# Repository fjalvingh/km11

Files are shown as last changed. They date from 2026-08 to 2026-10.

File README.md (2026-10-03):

# Pdp-11 KM11 Maintenance Module with LCD screen

This is supposed to become a KM11 maintenance module. It is a 2 slot card which should 
be placed in both KM11 slots of a PDP 11/05 or 11/10. It uses an ATTINY1616 (or 3216 
if I cannot make the code fit) and a set of i2c I/O adapters (PCF8574T) to read the data
from both slots for the KM11, and writes those to an LCD screen, offset on a cable.

The main PCB must be placed in the PDP 11/05. The LCD display and the switches sit on
a second, small PCB (`kicad/kmdisp`) at the end of a 20-way ribbon cable, so they can be
outside the pdp/11 in the 3D-printed console from `3d/`.

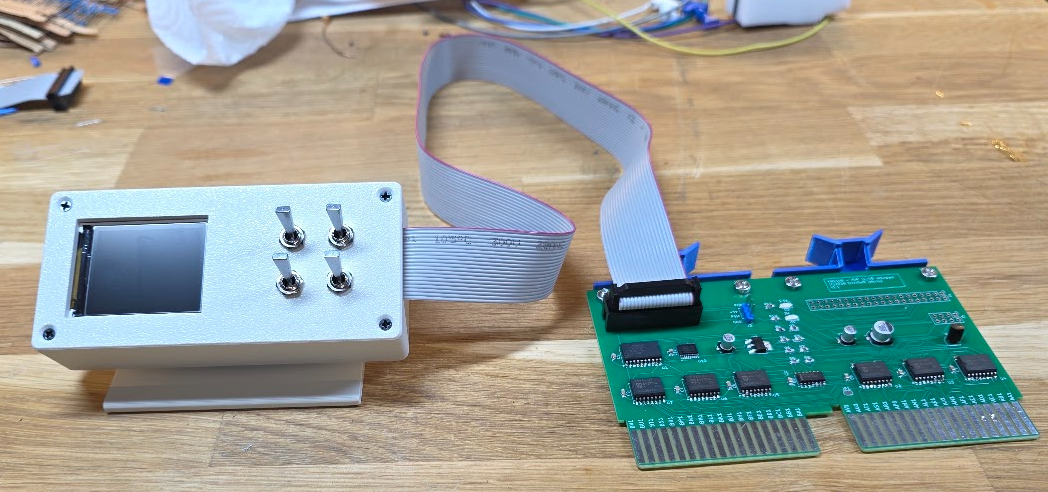
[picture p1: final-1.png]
The final version, in its 3d printed housing


## Hardware

The board uses:

* An ATTINY1616 (or ATTINY3216) as the controller
* Six PCF8574T I2C extenders to connect to both KM11 slots
* A 1.8" 160x128 LCD display to show the data

## Schematic and PCB views, version 1.1

The first version had some small issues which were repaired in this version.

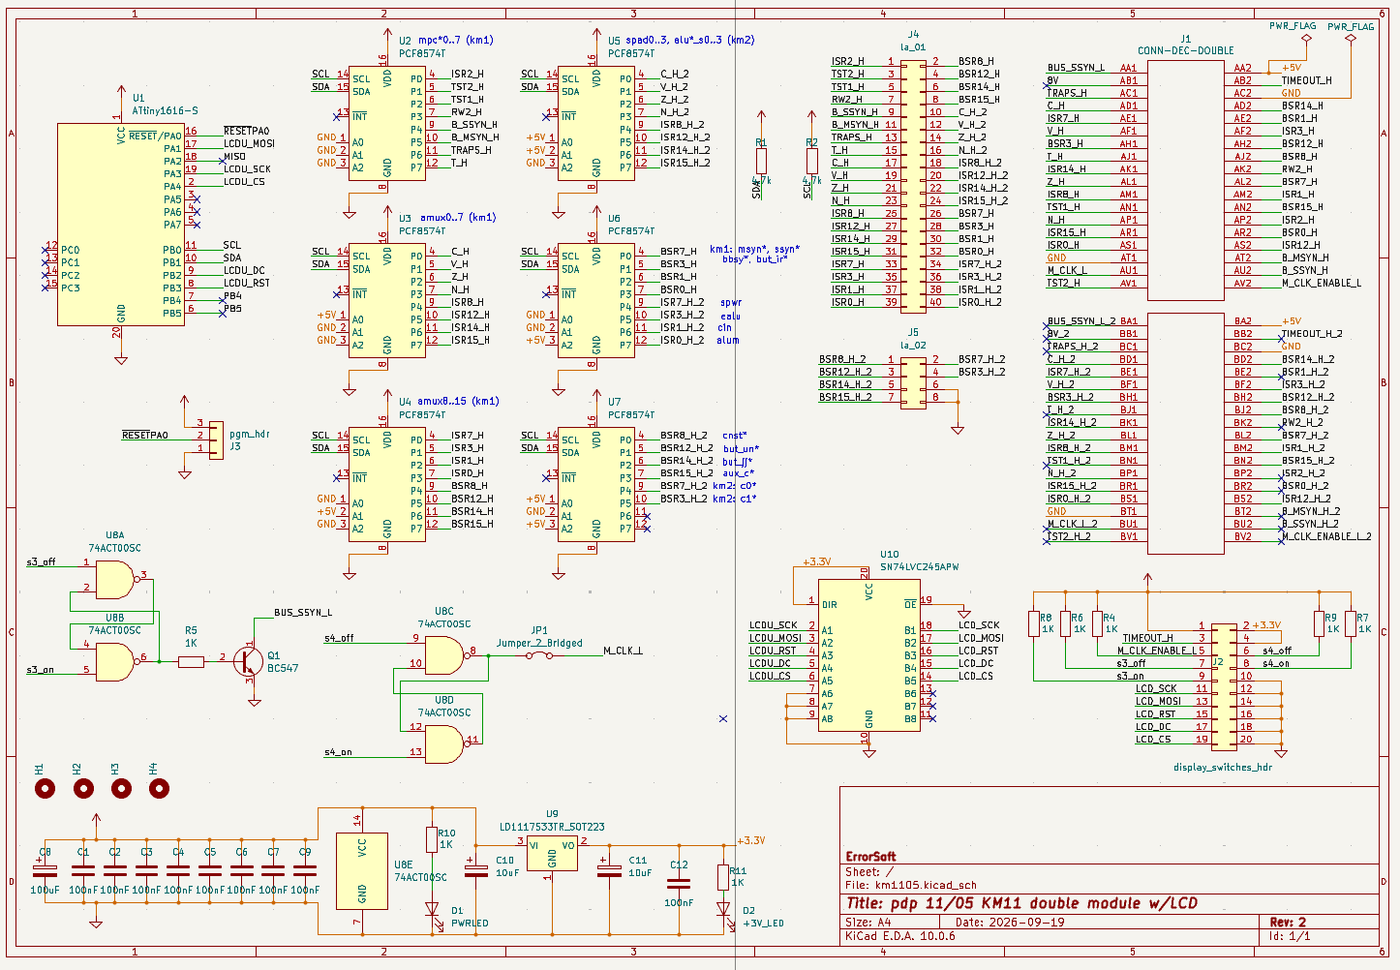
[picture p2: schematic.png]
schematic


## Display and switches board

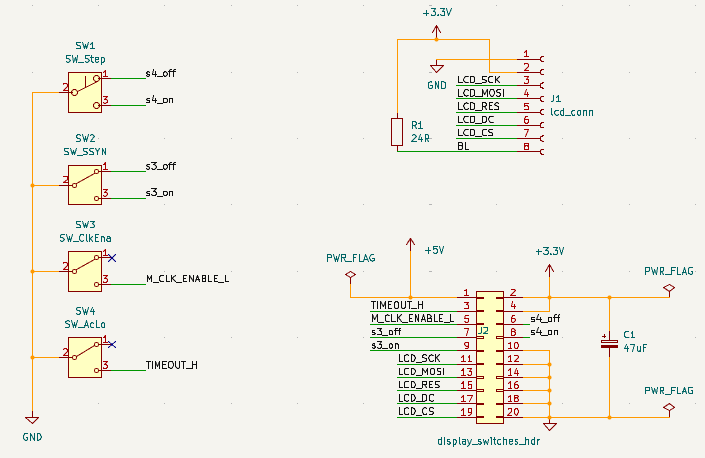
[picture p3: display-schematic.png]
The schematic for the display and switches board which resides in the housing


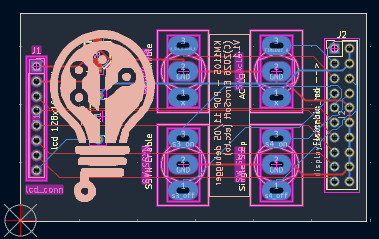
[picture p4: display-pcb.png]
The PCB for the display and switches board


## Code

The code was partially created by Claude, and does not use the usual libraries to save space 
in the Flash memory of the ATTINY1616 as it only has 16K. The code directly accesses registers
to control both the ST7735 LCD controller and the I2C extenders, and contains two fonts (5x7 
and 8x16).

At the time of writing the code takes about 9.3KB of the 16KB Flash available.

The code is a loop that reads all six extenders about ten times a second and repaints only
what changed. An earlier version of the screen, before the layout described below:

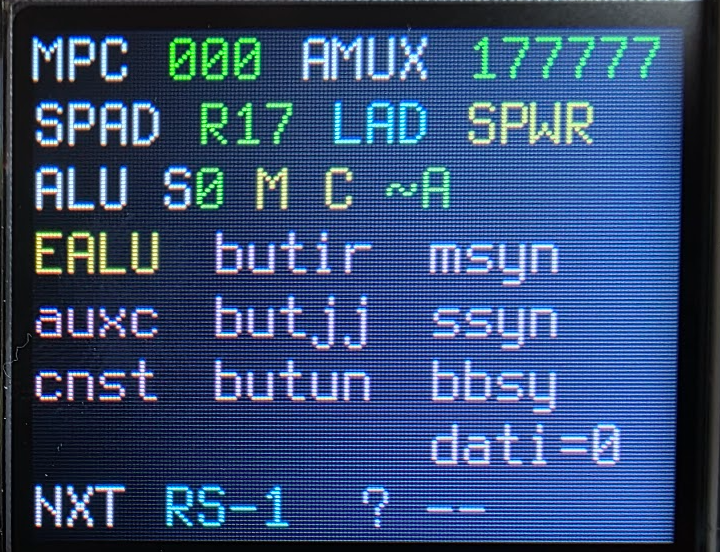
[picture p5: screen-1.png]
The screen, on a non-inserted card


### What the screen shows

```
MPC 302  AMUX 000000
SPAD R7  PC  spwr
ALU SF M c A
EALU BUTIR msyn
auxc butjj ssyn
cnst butun bbsy
          dati=0
NXT H-2  E OK
```

* **MPC** – the microprogram counter (octal). This is the *next* microstep, not the one whose
  signals are on the rest of the screen (KD11-B manual EK-KD11B-MM-001, 5.9).
* **AMUX** – the 16-bit data path (octal).
* **SPAD** – the scratchpad register being addressed, numbered as DEC does (R0–R17), with its
  use: SP, PC, SRC (R10), DST (R11), VEC (R12) or LAD (R17). Then SPWR, the scratchpad write.
* **ALU** – S, the raw S3–S0 function select (hex), then M (mode) and C (carry in), then the 74181 function they select (for example `A+B+1`). The function is grey when EALU is off, because then the ALU result does not reach the AMUX.
* **Flags**, in three columns: ALU/data path (EALU, AUXC, CNST), the microprogram branch tests
  (BUTIR, BUTJJ, BUTUN), and the Unibus (MSYN, SSYN, BBSY). Below the Unibus column is the bus
  cycle from C1/C0 with its code: DATI=0, DATIP=1, DATO=2, DATOB=3. The cycle name is lit while
  MSYN is asserted.
* **NXT** – DEC's name for the microstep the MPC points at, as used in the microprogram flow
  charts.
* **Status** (bottom right) – the microcode revision and the result of the microcode check (see
  below). A red `I2C:` followed by U numbers replaces it when an extender does not answer; the
  values that extender supplies are then not real.

Signals that are active low on the backplane (and shown dim on the original KM11, like the MPC
and ALU S) are inverted first, so everything on the screen is the logical value. Single signals
are **yellow and upper case** when asserted, **red and lower case** when negated.

Colours that mark a value:

* **dark blue background** – changed since the machine last moved. When single stepping, this
  shows what the last step did, and it stays until the next step.
* **white on red** – does not match the microcode listing (see below).

### Microcode check

While the processor is single stepped (M CLK ENABLE on, M CLK PULSE to step), the firmware
compares the lamps with DEC's microcode listing for the microword that just executed. It checks
ALU S/M/C, the scratchpad address, the four BUT lamps and AUXC. The status shows:

| Status | Meaning |
| --- | --- |
| `E OK` / `F OK` | the lamps match the listing |
| `E BAD` | some lamps do not match; they are drawn white on red |
| `SEQ?` | the MPC moved to an address the previous microword cannot branch to; the MPC turns red |
| `--` | nothing to check: no step seen yet, or the clock is running |

The first letter is the microcode revision of the M7261: `E` (1973) or `F` (1976), or `?` until
it is known. The card finds out by itself. The two revisions differ only in 14 microwords, and
the first time a step passes one of them, the AUXC lamp shows which revision is installed. Unary
instructions (CLR, INC, COM…) pass them. The revision is kept in the ATtiny's EEPROM.
`make REV=E eeprom`, `make REV=F eeprom` or `make REV=AUTO eeprom` sets or forgets it. Uploading
new firmware erases it, and it is learnt again.

The four switches are BUS SSYN, AC LO, M CLK PULSE (STEP) and M CLK ENABLE. The AC LO one sits
on the KM11 pin the 11/20 used for NO TIMEOUT, and the net is still called `TIMEOUT_H` for that
reason; on the 11/05 throwing it asserts BUS AC LO and starts the power-fail sequence.

`review.md` records the September 2026 check of the design and firmware against DEC's own
documentation, with the sources.

## Help with microcode debugging

The PDP 11/05 microcode for Rev.E and Rev.F can be browsed easily using [the microcode browser for the PDP 11/05](https://tools.etc.to/).

## Programming

To program the ATTINY1616 please follow the setup and instructions from [my 8bit bus display tool](https://github.com/fjalvingh/8bit-busdisplay). The source code is under src/. Two steps to do for a build:

* Use `make` to build the code, then
* Use `make upload` to upload the code to the board (with the programmer connected, obviously).

## The prototype

I made a small test setup to test driving the display:

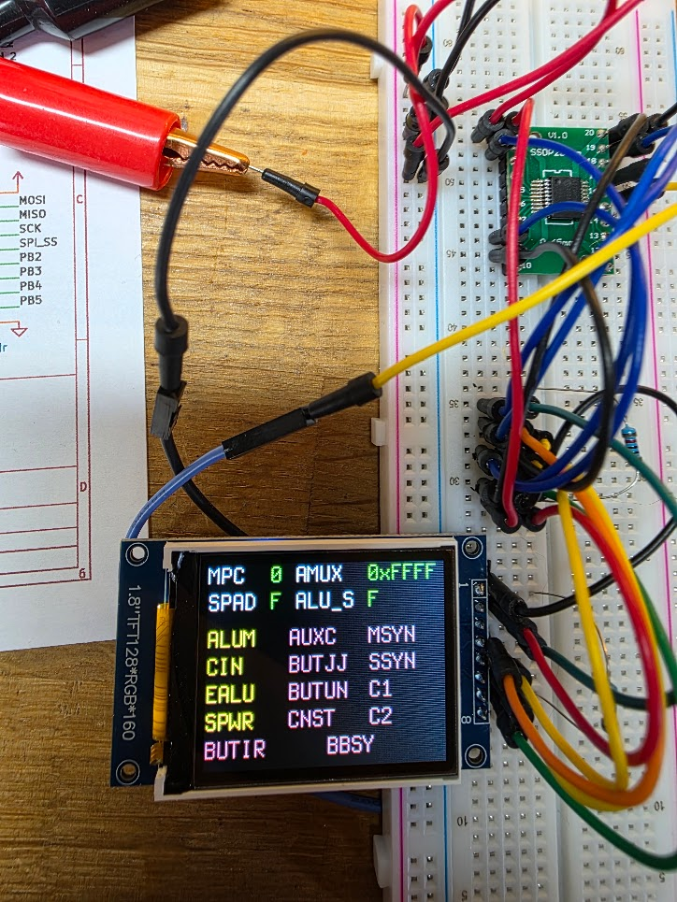
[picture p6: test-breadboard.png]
test setup


The initial idea was to use a fancy 2.25 landscape mode LCD to show the info, but after almost 4 hours
of testing and messing around with the code I gave up, I assume the display I got was defective. I was not helped by the fact that the second display tested, now the 1.8" display, was ALSO found to be defective, wasting another few hours. In the end I proved that of the 5 1.8" displays I have 1 was defective, and I had to pick that one for the test, obviously. Murphy in full working order.

## The first version in an actual PDP 11/10 (same as 11/05)

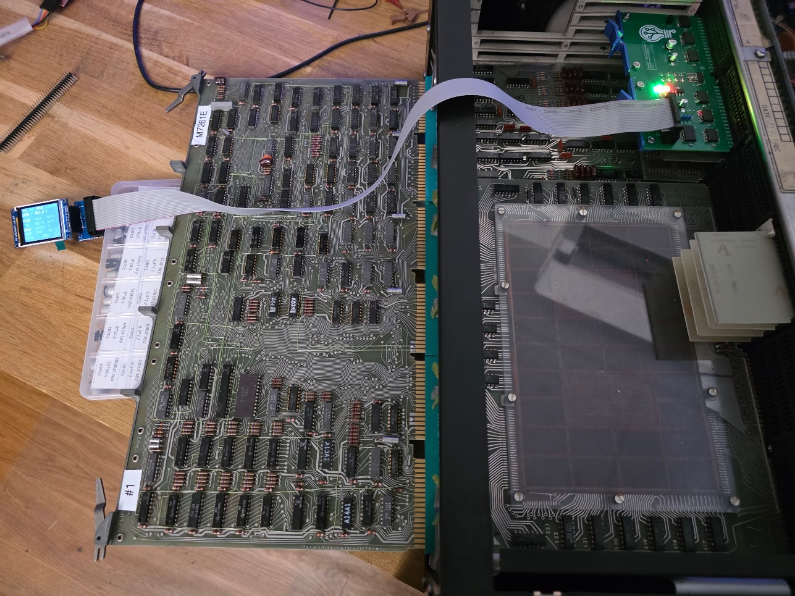
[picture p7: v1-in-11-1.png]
The V1 version in a PDP 11/10. This does not yet have its housing.


More closeup:

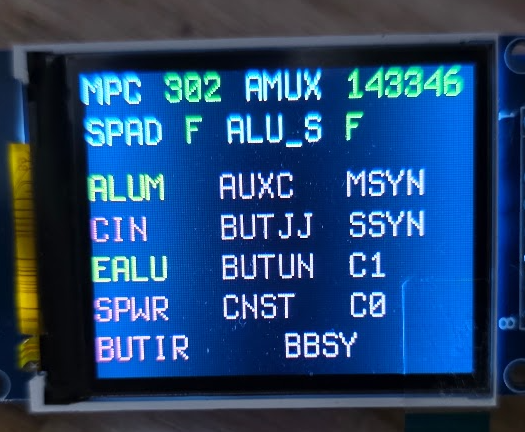
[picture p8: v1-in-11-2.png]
The old style display. On the side you can see the M7261 board on an extender

The microcode PC is at 302~oct~, which is H-2, part of the HALT instruction.

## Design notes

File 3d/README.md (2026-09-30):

# KM11 display console

Tilted desk console for the KM11's remote display: the display board
(`kicad/kmdisp`) carrying a 1.8" 128x160 ST7735S SPI TFT mounted landscape and
four MTS-102 toggle switches, on a ribbon cable back to the card.

`console.py` is the parametric source (CadQuery). Everything is driven from the
PARAMETERS block at the top; change a number and re-run.

## Parts

| STL | Size | Print orientation |
|---|---|---|
| `console_panel.stl` | 118.4 x 56 x 3.2 mm | face on the bed |
| `console_base.stl` | 118.4 x 56 x 22.8 mm | floor on the bed, walls up |
| `console_pedestal.stl` | 86 x 73.5 x 33.3 mm | as exported, base on the bed |

`console_assembly.stl` is for looking at only — do not slice it.

Assembled: **118.4 x 73.5 x 56 mm**, panel tilted 30 degrees off horizontal with
the back edge raised.

The panel is a flat plate. The base is the floor plus all four walls, with a
screw stud in each corner; the panel screws down onto them.

## What fixes the geometry

The switch holes and the display window are where the display board puts the
switches and the LCD; they must not move. `console.py` holds the board's KiCad
coordinates (`kc_sw`, `kc_board`, `kc_j2`) and places the board by its switch
cluster, so the checks it prints (board to walls, board to studs) come from the
real layout. The board spans x = -2.39 .. 56.99 mm in box coordinates, past
where the old right wall stood, which is why the box grew 4.4 mm on the right.
The left edge did not move.

The board hangs off the panel by its switches. Nothing else touches it. The
studs sit in the corners, 1.3–1.5 mm clear of its front and back edges.

## The ribbon

J2 is on the board's panel side, so the IDC plug's back, where the cable
leaves it, is just under the panel. Crimp the plug so the cable leaves toward
the switches' side (+x). It then runs flat out through a 27 x 3 mm notch at
the top of the right wall, centred on J2 (y = 15 .. 42 mm). The panel closes
the notch, so the cable is laid in rather than threaded through.

## How the display mounts

The glass stands 2.25 mm proud of its PCB and drops into the window from behind.
The window is cut to the measured glass outline (43.7 x 34.05 + 0.3 mm per
side), so nothing overlaps the glass. The module sits on the display board's
socket, so how far into the window it reaches depends on the board and socket
heights, not on the console.

## Print settings

PLA, 0.2 mm layer, 3 walls, 20% gyroid infill, **no supports**, no brim.

In its export orientation, no face on any part overhangs by more than 45 degrees
from vertical. Only the panel's edge chamfer and screw countersinks reach 45
degrees, because they are on the bed side. Don't re-orient the parts in the
slicer. Use 3 walls rather than 2, because the switch bushings, the panel screws
and the pedestal screws all thread into printed plastic.

## Hardware

- 8 x M3 countersunk self-tapping screws: 4 x 12 mm (panel to base studs),
  4 x 10 mm (base to pedestal)
- 4 x MTS-102 toggle switches with their nuts and washers, on the display board

## Assembly

1. Offer the base up to the pedestal and drive four M3 x 10 from inside the
   base into the pedestal. They are countersunk, so the heads end flush with
   the floor under the display board.
2. Fit the display board to the panel: toggles through their holes with the
   nuts on the outside, LCD glass in the window.
3. Plug in the ribbon, cable leaving toward the switches.
4. Lay the ribbon in the notch in the right wall and drop the panel onto the
   base. Then drive the four M3 x 12 corner screws into the studs.

## Check before printing

- **Depth.** The cavity is 18.8 mm from the panel's underside to the floor.
  The board, socket and switch stack were not measured into the model. Check
  that the back of the display board and its solder joints clear the floor, and
  that the pedestal screw heads under it are flush. If not, raise `box_t`.
- **Notch height.** `cable_h` = 3 mm assumes the IDC plug's back comes within a
  couple of mm of the panel. If the plug sits lower, the ribbon has to rise to
  the notch. Deepen the notch if that bend is too sharp.

## Panel layout

Measured from the panel's front-left corner, looking at the panel:

- display window 44.30 x 34.65 mm, spanning x = 10.05 .. 54.35 mm, y = 10.68 .. 45.33 mm
- switch holes 6.4 mm dia at x = 82.5 / 98.5 mm, y = 20 / 36 mm
- corner screws 5.4 mm in from the left and right edges, at y = 5.5 / 50.5 mm

## Regenerating

```bash
cd 3d
.venv/bin/python run_cadquery_model.py console.py --preview --strict
```

`run_cadquery_model.py`, `preview.py` and `mesh_io.py` are the headless
render helpers; they write `console_*_preview.png` next to each STL.

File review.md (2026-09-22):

# Design review, 22 September 2026

A check of the card (`kicad/km1105`), the display board (`kicad/kmdisp`) and the firmware (`src/`)
against DEC's own PDP-11/05 documentation. The fixes listed at the end were applied the same day;
the findings are kept here as the record of what was checked and why.

## Sources

All scans on bitsavers are images without a text layer, and the server answers a plain `curl` with
403: fetch with a browser `User-Agent`.

- **EK-KD11B-MM-001**, *KD11-B Processor Maintenance Manual*, January 1975.
  `https://www.bitsavers.org/pdf/dec/pdp11/1105/EK-KD11B-MM-001_Jan75.pdf`.
  Section 5.9 *KM11 Maintenance Panel*, 5.10 *Using KM11 Maintenance Panel*, Figure 5-1 (the KM-1
  and KM-2 overlays with DEC's B/D marks: *bright* / *dim when asserted*) and Table 5-4 (what every
  lamp and switch means). PDF pages 97–100.
- **PDP-11/05 engineering drawings, rev AH**, July 1976.
  `https://www.bitsavers.org/pdf/dec/pdp11/1105/1105_RevAH_Engineering_Drawings_Jul76.pdf`.
  The overlay drawings themselves, A-SS-5509081-0-9 (KM1) and -0-10 (KM2), PDF pages 186–187; the
  microprogram flow K-MP-KD11-B-1, pages 34–45, which is where the MPC values come from.
- **KM11 Maintenance Panel**, May 1970.
  `https://www.bitsavers.org/pdf/dec/pdp11/KM11_Maintenance_Panel_May70.pdf`.
  The W130 / W131 prints, D-BS-KM11-0-MB: which connector pin drives which lamp, the lamp
  positions on the W131, and the switch circuit.
- Jörg Hoppe's KM11 replica, `/d1/hobby/MiniMainframes/pdp/joerg_km11/`: the schematic the `J1`
  pin names were taken from, and his 11/05 overlay.
- `kicad-cli sch erc` / `pcb drc` on both boards, a parsed netlist of both, and a full firmware
  rebuild (`make -B`).

## Verified correct

- **Every `J1` pin name matches the W130 print**, pin for pin: BSR0 H = R2, BSR1 H = E2,
  BSR3 H = H1, BSR7 H = L2, BSR15 H = N2, BSR14 H = D2, BSR12 H = H2, BSR8 H = J2, ISR0 H = S1,
  ISR1 H = M2, ISR3 H = F2, ISR7 H = E1, ISR15 H = R1, ISR14 H = K1, ISR12 H = S2, ISR8 H = M1,
  N H = P1, Z H = L1, V H = F1, C H = D1, T H = J1, TRAPS H = C1, B MSYN H = T2, B SSYN H = U2,
  R/W2 H = K2, TST1 H = N1, TST2 H = V1, ISR2 H = P2; M CLK L = U1, M CLK ENABLE L = V2,
  TIME OUT H = B2, BUS SSYN L = A1, +5 V = A2, +8 V = B1, GND = C2 and T1.
- **The whole of `km11-signals.txt`** — all 28 lamps for both KM-1 and KM-2 — matches DEC's
  overlays. The W131 placement drawing puts lamp I1 at the *top* of the right-hand column and I25
  at the top left, with switches S3 (BUS SSYN), S1 (B2), S4 (M CLK), S2 (M CLK ENABLE) in exactly
  the positions Figure 5-1 draws BUS SSYN / AC LO / M CLK PULSE / M CLK EN, which fixes the
  orientation. Every one of the 48 expander inputs in the netlist lands on the pin `mapping.txt`
  says, so the card reads precisely what the overlay shows. Nothing is swapped, nothing is missing.
- KM-1 is wired to row A and KM-2 to row B of the same slot (manual §5.9 g), so the double-height
  card's A connector = KM-1 = the unsuffixed nets, B = KM-2 = the `_2` nets.
- The KM-2 MSYN and SSYN lamps that are left unconnected are "same as MSYN on KM-1" (Table 5-4).
  The MPC "is duplicated on both KM11 slots", so reading it once is enough.
- Polarity: MPC (D), BUT IR / BBUSY / SSYN / MSYN (D), AUX C / BUT JJ / BUT UN / CNST (D),
  C1 / C0 (D) are inverted by the firmware; AMUX (B), SPAD (B), ALUM / CIN / EALU / SPWR (B) are
  not. All agree with the overlay — except ALU S, see below.
- PCF8574 addresses 0x20–0x25 match the A0–A2 strapping of U2–U7. TWI0 on PB0/PB1 and SPI0 on
  PA1/PA3/PA4 are the ATtiny1616 default positions. U10 (74LVC245): DIR high, OE low, unused A
  inputs grounded, 5 V-tolerant inputs on a 3.3 V supply.
- The switch circuit is the W131 circuit: a cross-coupled 7400 latch driving M CLK L straight from
  a totem-pole output, a transistor pulling BUS SSYN L, a pull-up on M CLK ENABLE L, none on B2.
  Driving `M_CLK_L` from a 74ACT00 output is therefore by the book. The manual (§4.5) confirms
  M CLK L is an input to E039 pin 12 on the M7261; nothing on the processor drives it.
- On the display board the SPDT common (pin 2, the centre pad of the MTS-102 footprint) is ground
  in all four switches, matching the W131.
- ERC: six warnings only (dangling no-connect flags; LVC245 inputs tied to ground). DRC: one
  dangling via on `ISR1_H`. The display board is clean.
- Firmware: builds without warnings, 3998 bytes flash, 14 bytes RAM.

## Errors found

### 1. `ALU_S` polarity wrong in the firmware

DEC marks ALU S3–S0 "D" on the KM-2 overlay: dim when asserted, so the pin carries the signal
active low, exactly like MPC. `km11-signals.txt` and the README both say so. But
`src/signals.cpp` had `invertMask[3] = 0x00` ("SPAD and ALU_S, straight") because `mapping.txt`
had lost the star on `ALU_S`. The screen showed the complement of the ALU function code.

### 2. MPC truncated on screen, and shown in the wrong base

`kmmain.cpp` formatted the 8-bit MPC as two *decimal* digits, so anything from 100 up lost its
hundreds digit: the console halt loop at 300₈ / 302₈ (192 / 194) displayed as "92" / "94". DEC's
flow charts and §5.10 quote the MPC in octal ("the MPC should read 321₈, which is the contents of
the NXT field of LOC 100₈"), and 8 bits need three octal digits. AMUX was hex; the console lights
and everything in the manual are octal.

### 3. "C2" is DEC's "C0"

Table 5-4: "BUS C1 and C0 together signify the type of Unibus cycle": C1 C0 = 00 DATI, 01 DATIP,
10 DATO, 11 DATOB. The signal was called C2 in `km11-signals.txt`, `mapping.txt`, `signals.h`, on
the schematic and on the screen. The wire (U7 P4) is right, only the name was wrong. Jörg's
overlay has the same slip, which is where it came from.

### 4. The fourth switch is AC LO, not "No Timeout"

On the 11/05, KM11 pin B2 is BUS AC LO: "When actuated in the direction of the arrow (ON), AC LO
asserts BUS AC LO as long as the switch is ON" (Table 5-4; drawing 5509081-0-9 says the same). The
TIME OUT meaning belongs to the 11/20's W131. The display board called it `SW_NoTimeout` with a
"No Timeout" silkscreen. Throwing it starts the power-fail sequence. Note also §5.9 b: with the
manual clock enabled, bus error timeouts are disabled anyway, so a "no timeout" switch would be
redundant on this machine. The net keeps its historical name `TIMEOUT_H`; the labels say AC LO.

## Minor

- `kmmain.cpp` and the `Makefile` said U1 runs at 3.3 V; U1's VCC is +5 V in the netlist. The
  /2 prescaler is still fine, the reasoning was stale.
- §5.9 e: the MPC lamps show the address of the *next* microstep, not the current one.
- `pcfStatus` is computed but never shown. An expander that stops answering reads 0xFF, so its
  active-low flags silently show as negated. Some indicator would help. *(open)*
- There is no I²C bus recovery. If the ATtiny resets mid-read — UPDI programming does that — a
  PCF8574 can hold SDA low and every transaction then times out until a power cycle. Nine SCL
  pulses before `twiInit()` would clear it. *(open)*
- M CLK PULSE takes two ON/OFF throws per processor clock (§5.10). A momentary (ON)-OFF toggle
  for SW1 would be kinder than the MTS-102 ON-ON. *(open)*

## Fixes applied

- `src/signals.cpp`: `invertMask[3]` is `0xf0`, ALU_S inverted; comments corrected.
- `src/kmmain.cpp`: MPC three octal digits, AMUX six octal digits (`formatOctal`); "C2" → "C0";
  the 3.3 V comment corrected.
- `src/signals.h`: `SIG_C2` → `SIG_C0`, comments.
- `src/Makefile`: the 3.3 V comment corrected.
- `mapping.txt`, `km11-signals.txt`: `C2*` → `C0*`, `ALU_S*` marked active low.
- `kicad/km1105/km1105.kicad_sch`: annotation text "km2: c2*" → "km2: c0*".
- `kicad/kmdisp/kmdisp.kicad_sch`, `kmdisp.kicad_pcb`: SW4 is `SW_AcLo`, silkscreen "AC LO".
- `README.md`, `CLAUDE.md`: C0, AC LO, octal, "next microstep" noted.

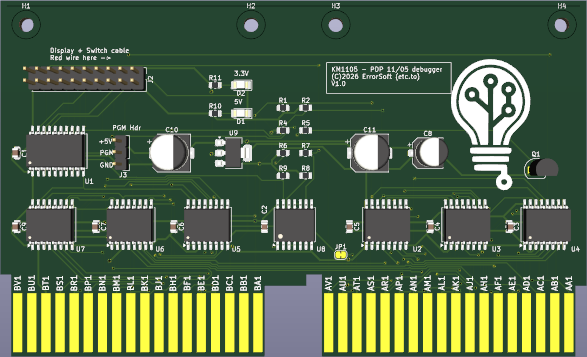
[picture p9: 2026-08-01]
3dview.png

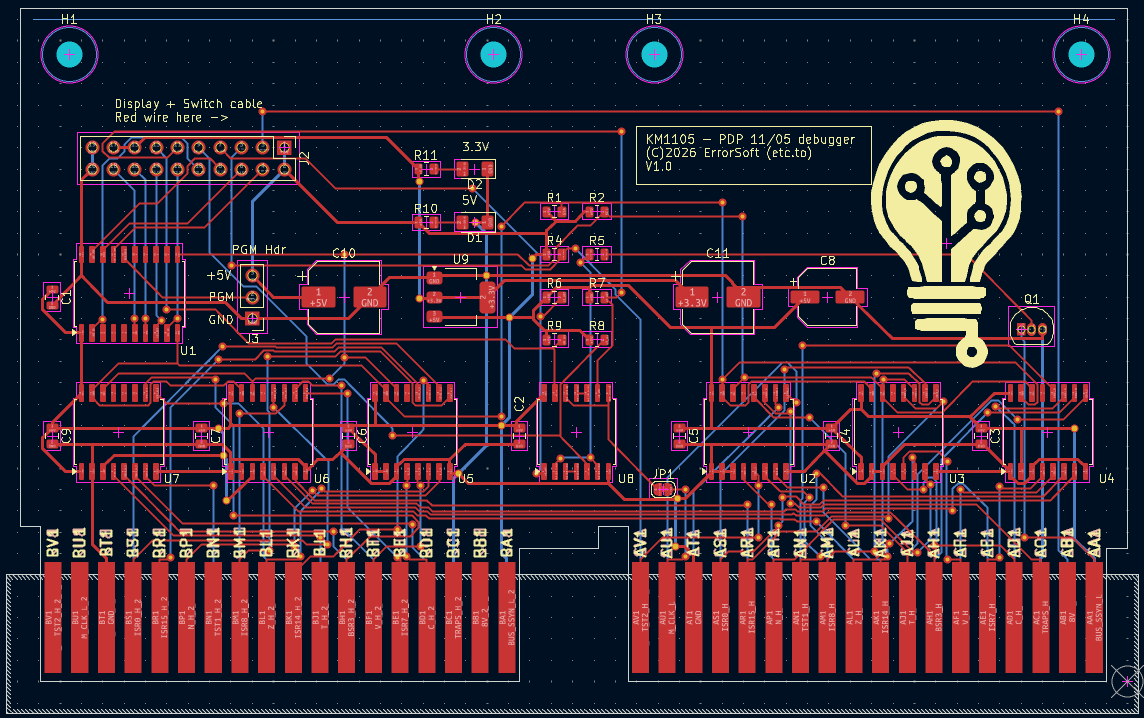
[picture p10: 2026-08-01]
pcblayout.png

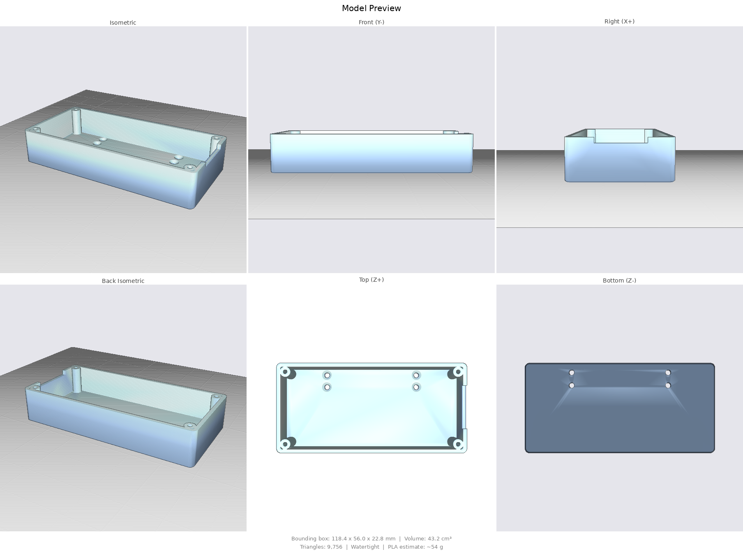
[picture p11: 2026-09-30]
3d/console_base_preview.png

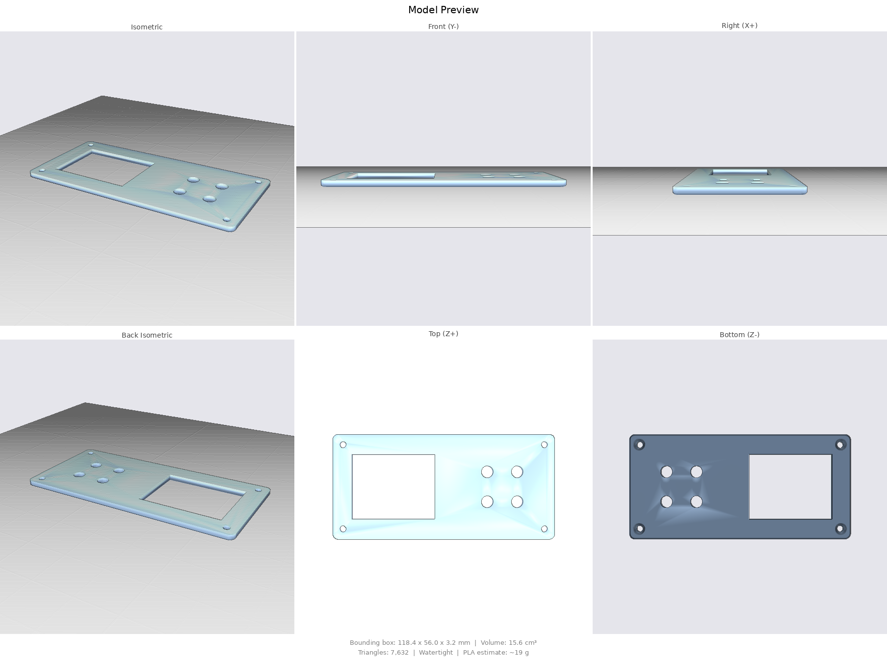
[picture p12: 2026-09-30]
3d/console_panel_preview.png

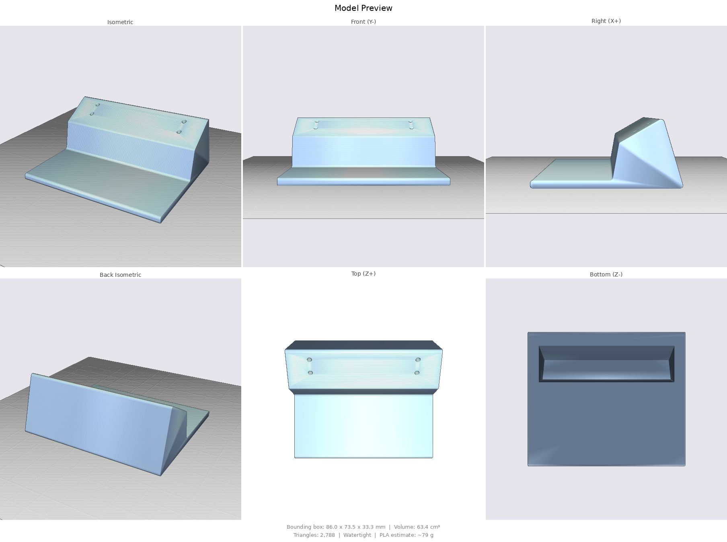
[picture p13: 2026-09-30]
3d/console_pedestal_preview.png

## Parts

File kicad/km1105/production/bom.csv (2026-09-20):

Designator | Footprint | Quantity | Value | LCSC Part #
C1, C12, C2, C3, C4, C5, C6, C7, C9 | 0805 | 9 | 100nF
C10, C11 | CP_Elec_4x4.5 | 2 | 10uF
C8 | CP_Elec_6.3x7.7 | 1 | 100uF
D1 | 1206 | 1 | PWRLED
D2 | 1206 | 1 | +3V_LED
J1 | CONN-DEC-DOUBLE | 1 | CONN-DEC-DOUBLE
J2 | PinHeader_2x10_P2.54mm_Vertical | 1 | display_switches_hdr
J3 | PinHeader_1x03_P2.54mm_Vertical | 1 | pgm_hdr
J4 | PinHeader_2x20_P2.54mm_Vertical | 1 | la_01
J5 | PinHeader_2x04_P2.54mm_Vertical | 1 | la_02
JP1 | SolderJumper-2_P1.3mm_Bridged_RoundedPad1.0x1.5mm | 1 | Jumper_2_Bridged
Q1 | TO-92_Inline | 1 | BC547
R1, R2 | 0805 | 2 | 4.7k
R10, R11, R4, R5, R6, R7, R8, R9 | 0805 | 8 | 1K
U1 | SOIC-20W_7.5x12.8mm_P1.27mm | 1 | ATtiny1616-S
U10 | TSSOP-20_4.4x6.5mm_P0.65mm | 1 | SN74LVC245APW
U2, U3, U4, U5, U6, U7 | SOIC-16W_7.5x10.3mm_P1.27mm | 6 | PCF8574T
U8 | SO-14_3.9x8.65mm_P1.27mm | 1 | 74ACT00SC
U9 | SOT-223-3_TabPin2 | 1 | LD1117S33TR_SOT223

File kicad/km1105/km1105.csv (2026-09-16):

Reference | Qty | Value | DNP | Exclude from BOM | Exclude from Board | Exclude from Simulation | Exclude from Position Files | Footprint | Datasheet
C1,C2,C3,C4,C5,C6,C7,C9 | 8 | 100nF |  |  |  |  | ${EXCLUDE_FROM_POS_FILES} | Capacitor_SMD:C_0805_2012Metric
C8 | 1 | 100uF |  |  |  |  | ${EXCLUDE_FROM_POS_FILES} | Capacitor_SMD:CP_Elec_6.3x7.7
C10,C11 | 2 | 10uF |  |  |  |  | ${EXCLUDE_FROM_POS_FILES} | Capacitor_SMD:CP_Elec_8x5.4
D1 | 1 | PWRLED |  |  |  |  | ${EXCLUDE_FROM_POS_FILES} | LED_SMD:LED_1206_3216Metric_Pad1.42x1.75mm_HandSolder
D2 | 1 | +3V_LED |  |  |  |  | ${EXCLUDE_FROM_POS_FILES} | LED_SMD:LED_1206_3216Metric_Pad1.42x1.75mm_HandSolder
J1 | 1 | CONN-DEC-DOUBLE |  |  |  |  | ${EXCLUDE_FROM_POS_FILES} | DEC-FLIP-CHIP:CONN-DEC-DOUBLE
J2 | 1 | display_switches_hdr |  |  |  |  | ${EXCLUDE_FROM_POS_FILES} | Connector_PinHeader_2.54mm:PinHeader_2x10_P2.54mm_Vertical
J3 | 1 | pgm_hdr |  |  |  |  | ${EXCLUDE_FROM_POS_FILES} | Connector_PinHeader_2.54mm:PinHeader_1x03_P2.54mm_Vertical
JP1 | 1 | Jumper_2_Bridged |  |  |  |  | ${EXCLUDE_FROM_POS_FILES} | Jumper:SolderJumper-2_P1.3mm_Bridged_RoundedPad1.0x1.5mm
Q1 | 1 | BC547 |  |  |  |  | ${EXCLUDE_FROM_POS_FILES} | Package_TO_SOT_THT:TO-92_Inline | https://www.onsemi.com/pub/Collateral/BC550-D.pdf
R1,R2 | 2 | 4.7k |  |  |  |  | ${EXCLUDE_FROM_POS_FILES} | Resistor_SMD:R_0805_2012Metric
R4,R5,R6,R7,R8,R9,R10,R11 | 8 | 1K |  |  |  |  | ${EXCLUDE_FROM_POS_FILES} | Resistor_SMD:R_0805_2012Metric
U1 | 1 | ATtiny1616-S |  |  |  |  | ${EXCLUDE_FROM_POS_FILES} | Package_SO:SOIC-20W_7.5x12.8mm_P1.27mm | http://ww1.microchip.com/downloads/en/DeviceDoc/ATtiny3216_ATtiny1616-data-sheet-40001997B.pdf
U2,U3,U4,U5,U6,U7 | 6 | PCF8574T |  |  |  |  | ${EXCLUDE_FROM_POS_FILES} | Package_SO:SOIC-16W_7.5x10.3mm_P1.27mm | https://www.nxp.com/docs/en/data-sheet/PCF8574_PCF8574A.pdf
U8 | 1 | 74ACT00SC |  |  |  |  | ${EXCLUDE_FROM_POS_FILES} | Package_SO:SOIC-14W_7.5x9mm_P1.27mm | http://www.ti.com/lit/gpn/sn74ls00
U9 | 1 | LD1117S33TR_SOT223 |  |  |  |  | ${EXCLUDE_FROM_POS_FILES} | Package_TO_SOT_SMD:SOT-223-3_TabPin2 | http://www.st.com/st-web-ui/static/active/en/resource/technical/document/datasheet/CD00000544.pdf

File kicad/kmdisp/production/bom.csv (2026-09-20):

Designator | Footprint | Quantity | Value | LCSC Part #
C1 | CP_Elec_4x3.9 | 1 | 47uF
J1 | PinSocket_1x08_P2.54mm_Vertical | 1 | lcd_conn
J2 | PinHeader_2x10_P2.54mm_Vertical | 1 | display_switches_hdr
R1 | R_Axial_DIN0207_L6.3mm_D2.5mm_P7.62mm_Horizontal | 1 | 24R
SW1 | SW_Toggle_MTS102 | 1 | SW_Step
SW2 | SW_Toggle_MTS102 | 1 | SW_SSYN
SW3 | SW_Toggle_MTS102 | 1 | SW_ClkEna
SW4 | SW_Toggle_MTS102 | 1 | SW_NoTimeout

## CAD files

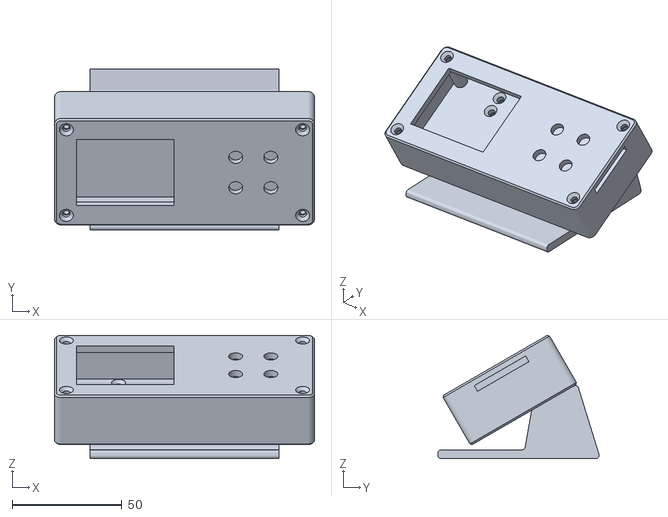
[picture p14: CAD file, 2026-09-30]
3d/console_assembly.stl
118.4 x 73.5 x 56.1

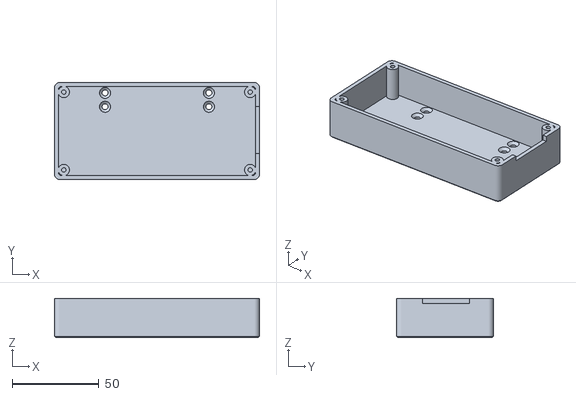
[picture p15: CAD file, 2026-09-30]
3d/console_base.stl
118.4 x 56.0 x 22.8

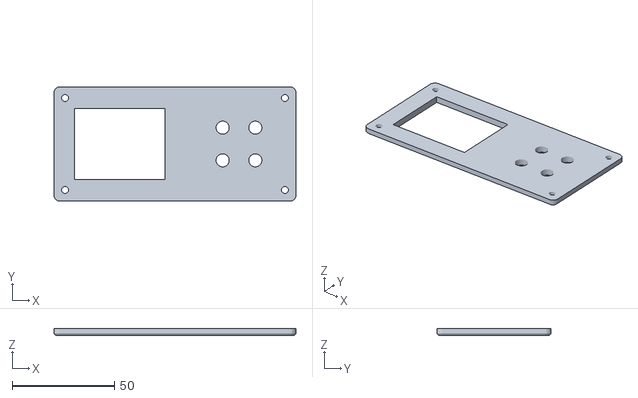
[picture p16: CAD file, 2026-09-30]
3d/console_panel.stl
118.4 x 56.0 x 3.20

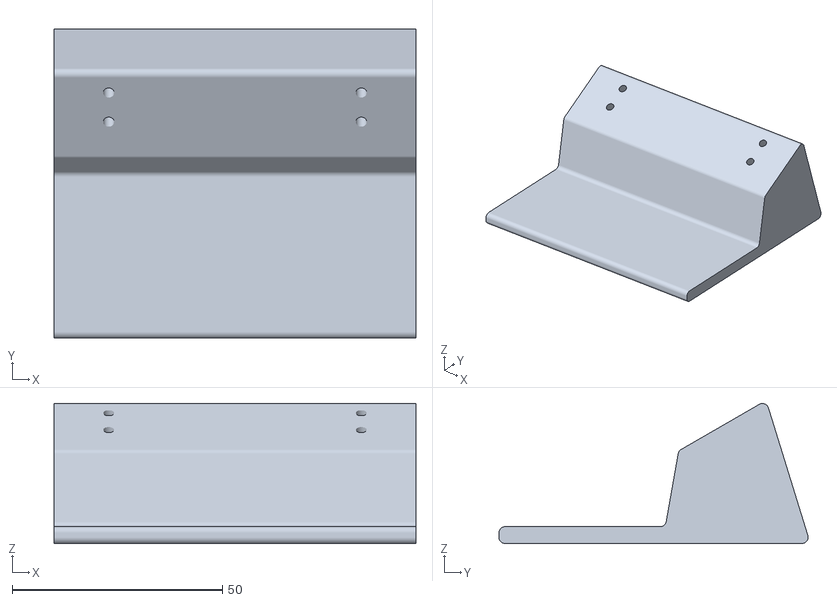
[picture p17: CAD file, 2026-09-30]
3d/console_pedestal.stl
86.0 x 73.5 x 33.3

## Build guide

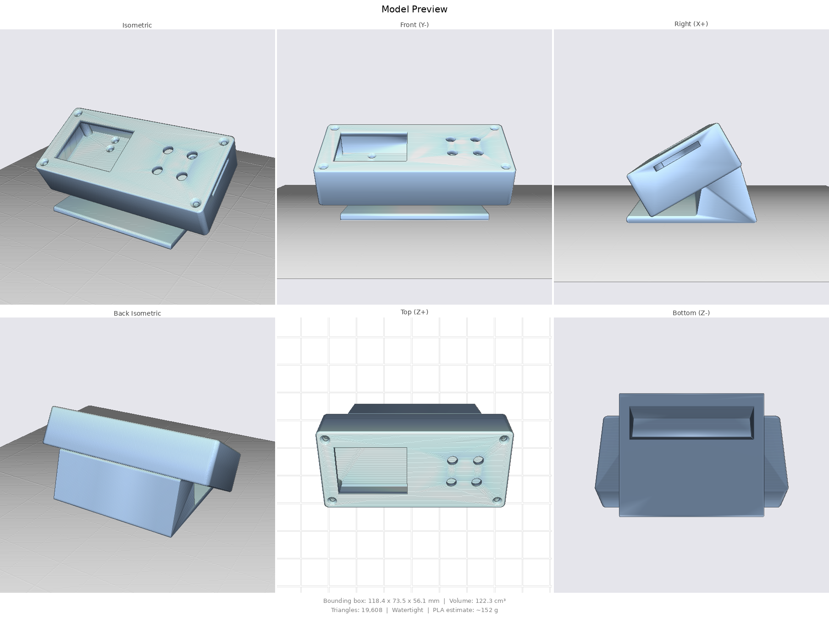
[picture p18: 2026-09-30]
3d/console_assembly_preview.png

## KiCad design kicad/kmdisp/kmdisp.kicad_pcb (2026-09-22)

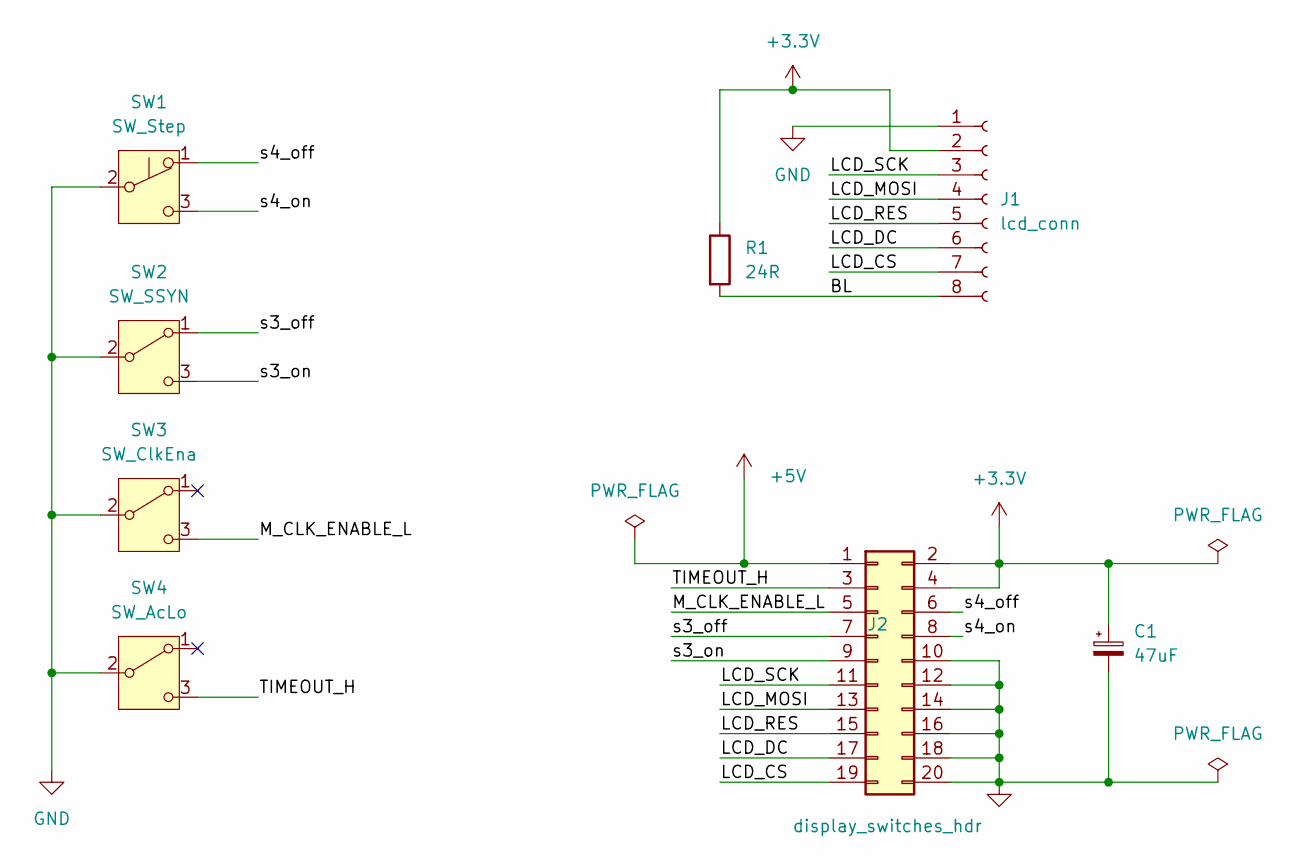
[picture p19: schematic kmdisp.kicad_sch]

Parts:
C1: 47uF; CP_Elec_4x3.9
J1: lcd_conn; PinSocket_1x08_P2.54mm_Vertical
J2: display_switches_hdr; PinHeader_2x10_P2.54mm_Vertical
R1: 24R; R_Axial_DIN0207_L6.3mm_D2.5mm_P7.62mm_Horizontal
SW1: SW_Step; SW_Toggle_MTS102
SW2: SW_SSYN; SW_Toggle_MTS102
SW3: SW_ClkEna; SW_Toggle_MTS102
SW4: SW_AcLo; SW_Toggle_MTS102

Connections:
+3.3V: C1.1, J1.2, J2.2, J2.4, R1.1
+5V: J2.1
/BL: J1.8, R1.2
/LCD_CS: J1.7, J2.19
/LCD_DC: J1.6, J2.17
/LCD_MOSI: J1.4, J2.13
/LCD_RES: J1.5, J2.15
/LCD_SCK: J1.3, J2.11
/M_CLK_ENABLE_L: J2.5, SW3.3 (C)
/TIMEOUT_H: J2.3, SW4.3 (C)
/s3_off: J2.7, SW2.1 (A)
/s3_on: J2.9, SW2.3 (C)
/s4_off: J2.6, SW1.1 (A)
/s4_on: J2.8, SW1.3 (C)
GND: C1.2, J1.1, J2.10, J2.12, J2.14, J2.16, J2.18, J2.20, SW1.2 (B), SW2.2 (B), SW3.2 (B), SW4.2 (B)

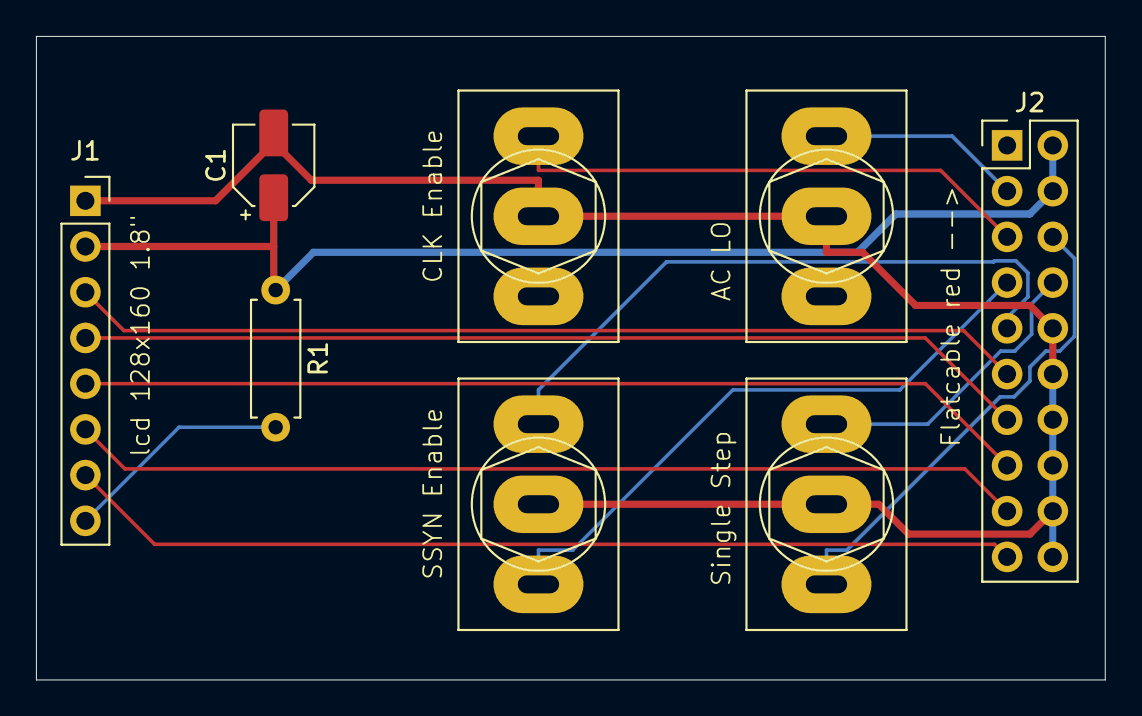
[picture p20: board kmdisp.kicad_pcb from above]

Board: 2 copper layers, 59.4 x 35.8 mm, 8 parts (0 on the bottom side), 14 nets.

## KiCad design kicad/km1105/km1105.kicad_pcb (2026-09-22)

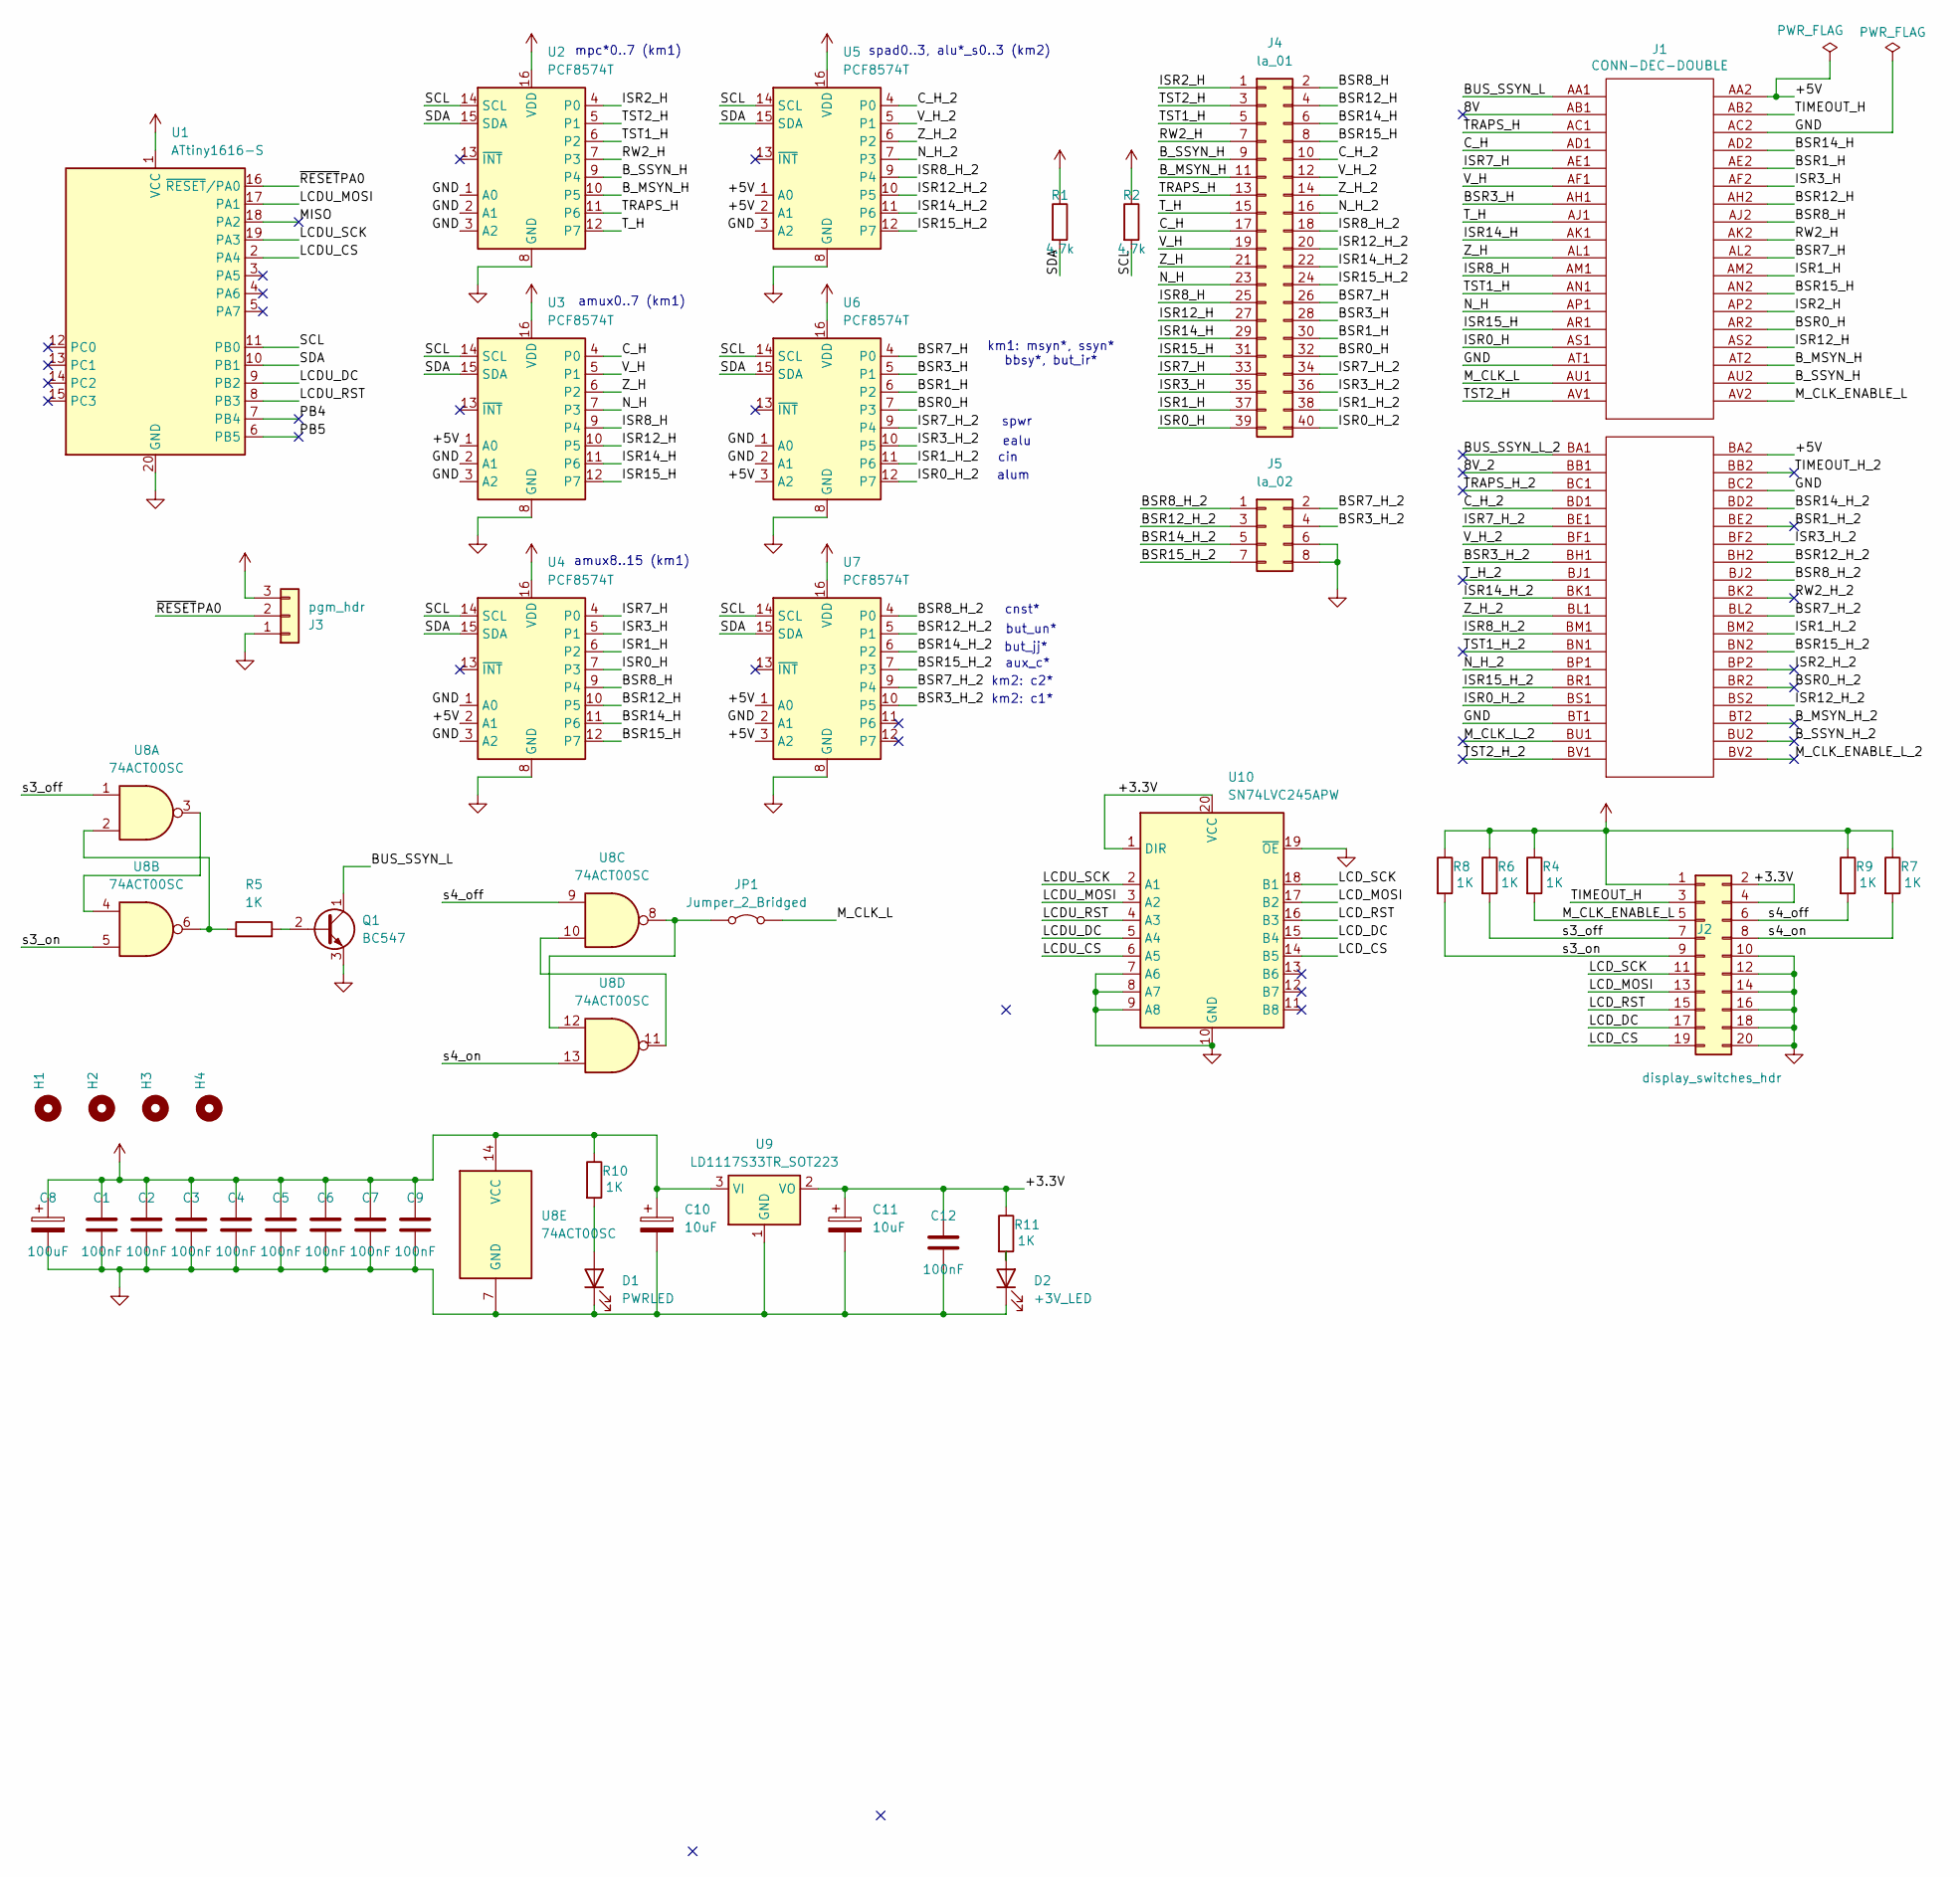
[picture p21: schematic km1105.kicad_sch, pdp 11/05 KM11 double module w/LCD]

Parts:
C1, C2, C3, C4, C5, C6, C7, C9, C12: 100nF; C_0805_2012Metric
C8: 100uF; CP_Elec_6.3x7.7
C10, C11: 10uF; CP_Elec_4x4.5
D1: PWRLED; LED_1206_3216Metric_Pad1.42x1.75mm_HandSolder
D2: +3V_LED; LED_1206_3216Metric_Pad1.42x1.75mm_HandSolder
H1, H2, H3, H4: MountingHole_3.2mm_M3
J1: CONN-DEC-DOUBLE
J2: display_switches_hdr; PinHeader_2x10_P2.54mm_Vertical
J3: pgm_hdr; PinHeader_1x03_P2.54mm_Vertical
J4: la_01; PinHeader_2x20_P2.54mm_Vertical
J5: la_02; PinHeader_2x04_P2.54mm_Vertical
JP1: Jumper_2_Bridged; SolderJumper-2_P1.3mm_Bridged_RoundedPad1.0x1.5mm
Q1: BC547; TO-92_Inline
R1, R2: 4.7k; R_0805_2012Metric
R4, R5, R6, R7, R8, R9, R10, R11: 1K; R_0805_2012Metric
U1: ATtiny1616-S; SOIC-20W_7.5x12.8mm_P1.27mm
U2, U3, U4, U5, U6, U7: PCF8574T; SOIC-16W_7.5x10.3mm_P1.27mm
U8: 74ACT00SC; SO-14_3.9x8.65mm_P1.27mm
U9: LD1117S33TR_SOT223; SOT-223-3_TabPin2
U10: SN74LVC245APW; TSSOP-20_4.4x6.5mm_P0.65mm

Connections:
+5V: C1.1, C2.1, C3.1, C4.1, C5.1, C6.1, C7.1, C8.1, C9.1, C10.1, J1.AA2, J1.BA2, J2.1, J3.3, R1.1, R2.1, R4.1, R6.1, R7.1, R8.1, R9.1, R10.1, U1.1 (VCC), U2.16 (VDD), U3.1 (A0), U3.16 (VDD), U4.2 (A1), U4.16 (VDD), U5.1 (A0), U5.2 (A1), U5.16 (VDD), U6.3 (A2), U6.16 (VDD), U7.1 (A0), U7.3 (A2), U7.16 (VDD), U8.14 (VCC), U9.3 (VI)
/8V: J1.AB1
/8V_2: J1.BB1
/+3.3V: C11.1, C12.1, J2.2, J2.4, R11.1, U9.2 (VO), U10.1 (DIR), U10.20 (VCC)
/BSR0_H: J1.AR2, J4.32, U6.7 (P3)
/BSR0_H_2: J1.BR2
/BSR1_H: J1.AE2, J4.30, U6.6 (P2)
/BSR1_H_2: J1.BE2
/BSR3_H: J1.AH1, J4.28, U6.5 (P1)
/BSR3_H_2: J1.BH1, J5.4, U7.10 (P5)
/BSR7_H: J1.AL2, J4.26, U6.4 (P0)
/BSR7_H_2: J1.BL2, J5.2, U7.9 (P4)
/BSR8_H: J1.AJ2, J4.2, U4.9 (P4)
/BSR8_H_2: J1.BJ2, J5.1, U7.4 (P0)
/BSR12_H: J1.AH2, J4.4, U4.10 (P5)
/BSR12_H_2: J1.BH2, J5.3, U7.5 (P1)
/BSR14_H: J1.AD2, J4.6, U4.11 (P6)
/BSR14_H_2: J1.BD2, J5.5, U7.6 (P2)
/BSR15_H: J1.AN2, J4.8, U4.12 (P7)
/BSR15_H_2: J1.BN2, J5.7, U7.7 (P3)
/BUS_SSYN_L: J1.AA1, Q1.1 (C)
/BUS_SSYN_L_2: J1.BA1
/B_MSYN_H: J1.AT2, J4.11, U2.10 (P5)
/B_MSYN_H_2: J1.BT2
/B_SSYN_H: J1.AU2, J4.9, U2.9 (P4)
/B_SSYN_H_2: J1.BU2
/C_H: J1.AD1, J4.17, U3.4 (P0)
/C_H_2: J1.BD1, J4.10, U5.4 (P0)
/ISR0_H: J1.AS1, J4.39, U4.7 (P3)
/ISR0_H_2: J1.BS1, J4.40, U6.12 (P7)
/ISR1_H: J1.AM2, J4.37, U4.6 (P2)
/ISR1_H_2: J1.BM2, J4.38, U6.11 (P6)
/ISR2_H: J1.AP2, J4.1, U2.4 (P0)
/ISR2_H_2: J1.BP2
/ISR3_H: J1.AF2, J4.35, U4.5 (P1)
/ISR3_H_2: J1.BF2, J4.36, U6.10 (P5)
/ISR7_H: J1.AE1, J4.33, U4.4 (P0)
/ISR7_H_2: J1.BE1, J4.34, U6.9 (P4)
/ISR8_H: J1.AM1, J4.25, U3.9 (P4)
/ISR8_H_2: J1.BM1, J4.18, U5.9 (P4)
/ISR12_H: J1.AS2, J4.27, U3.10 (P5)
/ISR12_H_2: J1.BS2, J4.20, U5.10 (P5)
/ISR14_H: J1.AK1, J4.29, U3.11 (P6)
/ISR14_H_2: J1.BK1, J4.22, U5.11 (P6)
/ISR15_H: J1.AR1, J4.31, U3.12 (P7)
/ISR15_H_2: J1.BR1, J4.24, U5.12 (P7)
/LCDU_CS: U1.2 (PA4), U10.6 (A5)
/LCDU_DC: U1.9 (PB2), U10.5 (A4)
/LCDU_MOSI: U1.17 (PA1), U10.3 (A2)
/LCDU_RST: U1.8 (PB3), U10.4 (A3)
/LCDU_SCK: U1.19 (PA3), U10.2 (A1)
/LCD_CS: J2.19, U10.14 (B5)
/LCD_DC: J2.17, U10.15 (B4)
/LCD_MOSI: J2.13, U10.17 (B2)
/LCD_RST: J2.15, U10.16 (B3)
/LCD_SCK: J2.11, U10.18 (B1)
/MISO: U1.18 (PA2)
/M_CLK_ENABLE_L: J1.AV2, J2.5, R4.2
/M_CLK_ENABLE_L_2: J1.BV2
/M_CLK_L: J1.AU1, JP1.2 (B)
/M_CLK_L_2: J1.BU1
/N_H: J1.AP1, J4.23, U3.7 (P3)
/N_H_2: J1.BP1, J4.16, U5.7 (P3)
/PB4: U1.7 (PB4)
/PB5: U1.6 (PB5)
/RW2_H: J1.AK2, J4.7, U2.7 (P3)
/RW2_H_2: J1.BK2
/SCL: R2.2, U1.11 (PB0), U2.14 (SCL), U3.14 (SCL), U4.14 (SCL), U5.14 (SCL), U6.14 (SCL), U7.14 (SCL)
/SDA: R1.2, U1.10 (PB1), U2.15 (SDA), U3.15 (SDA), U4.15 (SDA), U5.15 (SDA), U6.15 (SDA), U7.15 (SDA)
/TIMEOUT_H: J1.AB2, J2.3
/TIMEOUT_H_2: J1.BB2
/TRAPS_H: J1.AC1, J4.13, U2.11 (P6)
/TRAPS_H_2: J1.BC1
/TST1_H: J1.AN1, J4.5, U2.6 (P2)
/TST1_H_2: J1.BN1
/TST2_H: J1.AV1, J4.3, U2.5 (P1)
/TST2_H_2: J1.BV1
/T_H: J1.AJ1, J4.15, U2.12 (P7)
/T_H_2: J1.BJ1
/V_H: J1.AF1, J4.19, U3.5 (P1)
/V_H_2: J1.BF1, J4.12, U5.5 (P1)
/Z_H: J1.AL1, J4.21, U3.6 (P2)
/Z_H_2: J1.BL1, J4.14, U5.6 (P2)
/s3_off: J2.7, R6.2, U8.1
/s3_on: J2.9, R8.2, U8.5
/s4_off: J2.6, R9.2, U8.9
/s4_on: J2.8, R7.2, U8.13
/~RESETPA0: J3.2, U1.16 (~RESET/PA0)
GND: C1.2, C2.2, C3.2, C4.2, C5.2, C6.2, C7.2, C8.2, C9.2, C10.2, C11.2, C12.2, D1.1 (K), D2.1 (K), J1.AC2, J1.AT1, J1.BC2, J1.BT1, J2.10, J2.12, J2.14, J2.16, J2.18, J2.20, J3.1, J5.6, J5.8, Q1.3 (E), U1.20 (GND), U2.1 (A0), U2.2 (A1), U2.3 (A2), U2.8 (GND), U3.2 (A1), U3.3 (A2), U3.8 (GND), U4.1 (A0), U4.3 (A2), U4.8 (GND), U5.3 (A2), U5.8 (GND), U6.1 (A0), U6.2 (A1), U6.8 (GND), U7.2 (A1), U7.8 (GND), U8.7 (GND), U9.1 (GND), U10.7 (A6), U10.8 (A7), U10.9 (A8), U10.10 (GND), U10.19 (~OE)
unnamed: D1.2 (A), R10.2
unnamed: D2.2 (A), R11.2
unnamed: JP1.1 (A), U8.8, U8.12
unnamed: Q1.2 (B), R5.2
unnamed: R5.1, U8.2, U8.6
unnamed: U8.3, U8.4
unnamed: U8.10, U8.11

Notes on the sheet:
cin
but_un*
km2: c1*
but_jj*
amux8..15 (km1)
spwr
ealu
alum
amux0..7 (km1)
km2: c2*
spad0..3, alu*_s0..3 (km2)
km1: msyn*, ssyn* bbsy*, but_ir*
aux_c*
mpc*0..7 (km1)
cnst*

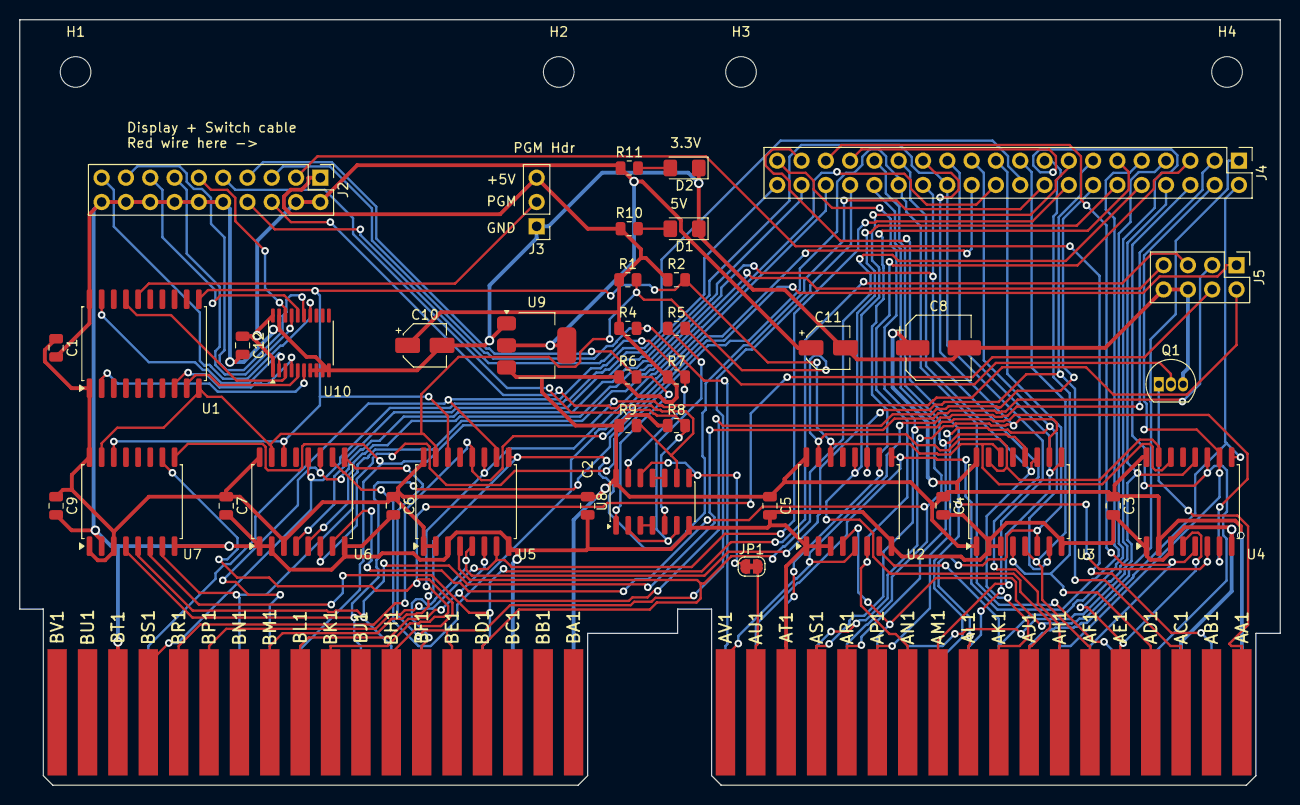
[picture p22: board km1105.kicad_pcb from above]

Board: 2 copper layers, 131.7 x 80.0 mm, 45 parts (0 on the bottom side), 77 nets.

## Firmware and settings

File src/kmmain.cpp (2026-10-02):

#include <avr/io.h>
#include <util/delay.h>
#include <avr/pgmspace.h>
#include <string.h>

#include "lcd.h"
#include "font5x7.h"
#include "pcf8574.h"
#include "signals.h"
#include "microtags.h"
#include "mcheck.h"

// The 20MHz fuse only selects the oscillator; the main clock still comes out of
// a divide-by-6 prescaler after reset, so the prescaler has to be set here for
// F_CPU (and with it _delay_ms and the SPI clock) to mean anything.
//
// It is set to divide by two, NOT switched off. U1 runs on +5V, so the part
// would be in spec at 20MHz, but nothing here needs it: 10MHz is plenty, the
// SPI and I2C dividers are tuned to it, and it keeps the edges on the ribbon
// gentler. If fuse2 is left at the 16MHz default this gives 8MHz instead,
// which is also fine - only the timings scale.
static void clockInit() {
	_PROTECTED_WRITE(CLKCTRL.MCLKCTRLB, CLKCTRL_PDIV_2X_gc | CLKCTRL_PEN_bm);
}

// One text line is FONT_HEIGHT pixels; leave one pixel of leading between them.
#define LINE_H (FONT_HEIGHT + 1)
static inline uint16_t lineY(uint8_t line, const Font *font = &FontSmall) {
	return (uint16_t) line * (font->height + 1);
}

static inline uint16_t lineX(uint8_t column, const Font *font = &FontSmall) {
	return (uint16_t) column * (font->width + 1);
}

// Unsigned decimal into a caller supplied buffer, right aligned in `width` and
// space padded. Small enough to be worth having instead of pulling in printf,
// which would cost well over a kilobyte of flash.
static void formatNumber(char *buf, uint16_t value, uint8_t width) {
	buf[width] = '\0';
	for(uint8_t i = width; i-- > 0;) {
		buf[i] = (char) ('0' + (value % 10));
		value /= 10;
		if(value == 0 && i > 0) {
			while(i-- > 0)
				buf[i] = ' ';
			break;
		}
	}
}

static void formatHex(char *buf, uint16_t value, uint8_t width) {
	buf[width] = '\0';
	for(uint8_t i = width; i-- > 0;) {
		int c = (value % 16);
		if(c > 9)
			c += 'A' - 10;
		else
			c += '0';

		buf[i] = (char) c;

		value /= 16;
		if(value == 0 && i > 0) {
			while(i-- > 0)
				buf[i] = '0';
			break;
		}
	}
}

// Zero padded octal, which is what everything PDP-11 is written in: the MPC
// addresses in the microprogram flow charts are octal, and so are the console
// lights the AMUX value gets compared with.
static void formatOctal(char *buf, uint16_t value, uint8_t width) {
	buf[width] = '\0';
	for(uint8_t i = width; i-- > 0;) {
		buf[i] = (char) ('0' + (value & 7));
		value >>= 3;
	}
}

// Paints a test pattern: a title, some coloured signal-ish text, and the whole
// printable character set laid out the way the signal display will use it.
static void drawTestScreen() {
	lcdFill(LCD_BLACK);

	lcdDrawText_P(0, lineY(0), PSTR("KM11 11/05 MAINT"), LCD_YELLOW, LCD_BLACK);

	lcdDrawText_P(0, lineY(1), PSTR("BSR"), LCD_GREY, LCD_BLACK);
	lcdDrawText_P(4 * FONT_CELL_W, lineY(1), PSTR("0000 1111"), LCD_GREEN, LCD_BLACK);
	lcdDrawText_P(0, lineY(2), PSTR("ISR"), LCD_GREY, LCD_BLACK);
	lcdDrawText_P(4 * FONT_CELL_W, lineY(2), PSTR("1010 0101"), LCD_RED, LCD_BLACK);

	// Every printable character, wrapped to the screen width. This is the part
	// that shows the font table and the glyph writer agree.
	uint8_t line = 4;
	uint16_t x = 0;
	for(uint8_t c = FONT_FIRST_CHAR; c <= FONT_LAST_CHAR; c++) {
		if(x + FONT_CELL_W > LCD_W) {
			x = 0;
			line++;
			if(lineY(line) + FONT_HEIGHT > LCD_H)
				break;
		}
		x = lcdDrawChar(x, lineY(line), (char) c, LCD_WHITE, LCD_BLACK);
	}
}

// Wiring test. No SPI, no protocol: SPI0 is switched off and all five lines to
// the display are toggled by hand, each at its own frequency, so any one of
// them can be identified on a slow scope or a multimeter without triggering on
// anything. Probe at the *display end* of the ribbon, not at the MCU:
//
//   CS   (PA4, J2.19, kmdisp J1.7)  8 Hz
//   MOSI (PA1, J2.13, kmdisp J1.4)  4 Hz
//   SCK  (PA3, J2.11, kmdisp J1.3)  2 Hz
//   DC   (PB2, J2.17, kmdisp J1.6)  1 Hz
//   RST  (PB3, J2.15, kmdisp J1.5)  0.5 Hz
//
// A line that does not move is a break between the pin and the panel. Check the
// amplitude while you are there: the lines leave the ATtiny at 5V and go
// through U10 (74LVC245 on 3.3V), so a 3.3V swing at the display end is right
// and a 5V one means the signal is bypassing U10.
__attribute__((unused)) static void pinTestLoop() {
	SPI0.CTRLA = 0;						// hand PA1/PA3 back to the port

	uint8_t tick = 0;
	for(;;) {
		if(tick & 0x01) LCD_SPI_PORT.OUTSET = LCD_CS_bm;    else LCD_SPI_PORT.OUTCLR = LCD_CS_bm;
		if(tick & 0x02) LCD_SPI_PORT.OUTSET = LCD_MOSI_bm;  else LCD_SPI_PORT.OUTCLR = LCD_MOSI_bm;
		if(tick & 0x04) LCD_SPI_PORT.OUTSET = LCD_SCK_bm;   else LCD_SPI_PORT.OUTCLR = LCD_SCK_bm;
		if(tick & 0x08) LCD_CTRL_PORT.OUTSET = LCD_DC_bm;   else LCD_CTRL_PORT.OUTCLR = LCD_DC_bm;
		if(tick & 0x10) LCD_CTRL_PORT.OUTSET = LCD_RST_bm;  else LCD_CTRL_PORT.OUTCLR = LCD_RST_bm;

		tick++;
		_delay_ms(62);
	}
}

// Read the controller back and report it on a spare pin, because with a dead
// panel there is nowhere else to put the answer. This is the test that decides
// whether the controller is listening at all: everything up to now has only
// proved the ATtiny is talking.
//
// The read is half duplex on SDA, since the module has no SDO pin. Watch PB5
// (U1 pin 6, spare, not on the ribbon) with the scope: each round is a 20ms
// high start marker, then 40 bits at 1ms each, MSB first, high = 1, so the
// five bytes can be read straight off the trace.
//
// Nothing is skipped for dummy clocks, so an answer may appear shifted a bit or
// a byte into the stream. What matters is the shape:
//
//   0x85 0x85 0x52 somewhere in it   an ST7789 answering. The controller is
//                                    alive and the fault is in the init values
//   any structured pattern           something is answering: send me the bytes
//   all ones                         nothing drives SDA back. Either the
//                                    controller ignores reads, or it is not
//                                    responding at all
//   all zeros                        SDA is being held low somewhere
__attribute__((unused)) static void idReportLoop() {
	LCD_CTRL_PORT.DIRSET = PIN5_bm;

	for(;;) {
		uint8_t id[5];
		lcdReadRegister(0x04, id, 5);	// RDDID

		LCD_CTRL_PORT.OUTSET = PIN5_bm;	// start marker
		_delay_ms(20);
		LCD_CTRL_PORT.OUTCLR = PIN5_bm;
		_delay_ms(5);

		for(uint8_t byte = 0; byte < 5; byte++) {
			for(uint8_t bit = 0; bit < 8; bit++) {
				if(id[byte] & (0x80 >> bit))
					LCD_CTRL_PORT.OUTSET = PIN5_bm;
				else
					LCD_CTRL_PORT.OUTCLR = PIN5_bm;
				_delay_ms(1);
			}
		}
		LCD_CTRL_PORT.OUTCLR = PIN5_bm;

		_delay_ms(500);
	}
}

// Panel bring-up mode. Set to 0 once the display works to get the text screen.
//
// The modes are a ladder, each dropping more assumptions than the last: the
// text screen needs everything to be right, mode 1 needs the geometry but not
// the font, mode 4 needs neither, mode 2 needs no SPI at all.
//
//   0 = the real text screen
//   1 = fill the panel with cycling colours, through the normal path
//   2 = pin wiggle, no SPI at all, for checking the wiring end to end
//   3 = read the controller ID back and report it on PB5
//   4 = flood the raw frame memory, ignoring panel size and offsets
//
// Set it in the Makefile (make DIAG_MODE=2); this is only the fallback for a
// compile that does not pass one.
#ifndef DIAG_MODE
	#define DIAG_MODE 1
#endif

// No white and no black in the cycle, deliberately. A pixel the controller
// never writes keeps whatever it last received, so with white in the rotation
// every missed pixel ends up white and stays white - which reads as "white
// lines" and hides which frame actually lost them. Against these four, a stale
// pixel shows up as the wrong colour instead.
static const uint16_t diagColors[4] = { LCD_RED, LCD_GREEN, LCD_BLUE, LCD_YELLOW };

// Fills the panel through the normal drawing path: real geometry, real offsets,
// real rotation. Once the controller is known to be alive this is the honest
// test, because it exercises exactly what the text screen will use.
//
// Every other pass draws stripes instead of a flat fill, one lcdFillRect per
// stripe, which is what tells the two failure modes apart:
//
//   stale pixels land on stripe boundaries   whole transactions are being lost,
//                                            so the fault is in the command or
//                                            window handling
//   stale pixels scattered inside stripes    bytes are being dropped mid
//                                            stream: a timing or signal
//                                            integrity problem, so try
//                                            LCD_SPI_DIV 64 or 128
__attribute__((unused)) static void diagLoop() {
	uint8_t ix = 0;
	for(;;) {
		lcdFill(diagColors[ix & 3]);
		_delay_ms(1000);

		// Eight pixel stripes, alternating, each its own window and RAMWR.
		for(uint16_t y = 0; y < LCD_H; y += 8) {
			uint16_t h = (y + 8 > LCD_H) ? (LCD_H - y) : 8;
			lcdFillRect(0, y, LCD_W, h, ((y >> 3) & 1) ? LCD_MAGENTA : LCD_CYAN);
		}
		_delay_ms(1000);

		ix++;
	}
}

// Fills the whole frame memory instead, ignoring panel size and offsets. Keep
// this for a panel that shows nothing at all; it addresses more memory than the
// glass has, so gaps and edge artefacts here do not necessarily mean anything
// is wrong with the drawing path.
__attribute__((unused)) static void ramFloodLoop() {
	uint8_t ix = 0;
	for(;;) {
		lcdInit();						// pulses RST every pass
		lcdFillRam(diagColors[ix]);
		ix++;
		if(ix >= 5)
			ix = 0;
		_delay_ms(1000);
	}
}

__attribute__((unused)) static void textLoop() {
	// Repaint forever rather than painting once and idling: on a scope or
	// analyser this gives a repeating SPI burst to trigger on, and on the panel
	// the counter proves the loop is still running even if the image is wrong.
	// The colour of the counter cycles too, so a frozen frame is obvious.
	static const uint16_t cycle[4] = { LCD_WHITE, LCD_GREEN, LCD_CYAN, LCD_MAGENTA };

	uint16_t frame = 0;
	for(;;) {
		drawTestScreen();

		char buf[6];
		formatNumber(buf, frame, 5);
		lcdDrawText_P(0, lineY(3), PSTR("FRAME"), LCD_GREY, LCD_BLACK);
		lcdDrawText(6 * FONT_CELL_W, lineY(3), buf, cycle[frame & 3], LCD_BLACK);

		frame++;
		_delay_ms(500);
	}
}

__attribute__((unused)) static uint8_t pcfStatus;
static uint16_t currentBg = LCD_BLACK;

// Background behind a value that differs from the machine state before the
// last change, so a single step shows what it moved. Dark enough that the
// red, yellow, green and cyan text stays readable on it.
static constexpr uint16_t LCD_HILITE = rgb565(0, 0, 150);

// Shows a flag in place: asserted is upper case in yellow, negated lower case
// in red, so the state reads even without the colour. Works on a RAM copy
// because it changes the case. Returns the x just past the text.
static uint16_t flagText(uint16_t x, uint16_t y, char *name, bool on, uint8_t style, const Font *font = &FontSmall);

// Same, for a name in flash.
static uint16_t flagDisp(uint16_t x, uint16_t y, const char *name, bool on, uint8_t style, const Font *font = &FontSmall) {
	char buf[8];
	strncpy_P(buf, name, sizeof buf - 1);
	buf[sizeof buf - 1] = '\0';
	return flagText(x, y, buf, on, style, font);
}

// How a value is drawn: plain, changed by the last step (dark blue behind
// it), or contradicting the microcode listing (white on red, which wins).
enum Style : uint8_t { ST_PLAIN, ST_CHANGED, ST_BAD };

static uint8_t styleOf(bool changed, bool bad) {
	return bad ? ST_BAD : changed ? ST_CHANGED : ST_PLAIN;
}

static uint16_t styleBg(uint8_t style) {
	return style == ST_BAD ? LCD_RED : style == ST_CHANGED ? LCD_HILITE : currentBg;
}

static uint16_t styleFg(uint8_t style, uint16_t fg) {
	return style == ST_BAD ? LCD_WHITE : fg;
}

static uint16_t flagText(uint16_t x, uint16_t y, char *name, bool on, uint8_t style, const Font *font) {
	if(!on) {
		for(char *p = name; *p != '\0'; p++)
			if(*p >= 'A' && *p <= 'Z')
				*p += 'a' - 'A';
	}
	return lcdDrawText(x, y, name, styleFg(style, on ? LCD_YELLOW : LCD_LIGHTRED), styleBg(style), font);
}

// The last sample off the expanders. Everything the screen draws comes out of
// here, so a failed read leaves the previous frame's numbers on the glass
// rather than blanking them.
__attribute__((unused)) static KmSignals currentSignals;
// The state before the last change, which drawScreen() highlights against.
__attribute__((unused)) static KmSignals previousSignals;

// Pads buf with spaces to `width` characters, so a short text overwrites a
// longer one left by the previous frame.
static void padTo(char *buf, uint8_t width) {
	uint8_t n = (uint8_t) strlen(buf);
	while(n < width)
		buf[n++] = ' ';
	buf[n] = '\0';
}

// What the processor keeps in each scratchpad register (KD11-B manual, Table
// 4-3). R13..R16 are unused. Three cells each so a shorter name overwrites a
// longer one.
static const char spadNames[16][4] PROGMEM = {
	"   ", "   ", "   ", "   ", "   ", "   ", "SP ", "PC ",
	"SRC", "DST", "VEC", "   ", "   ", "   ", "   ", "LAD",
};

// The 74181 functions as the KD11-B uses them: its A and B legs are active low
// (KD11-B manual 4.3.5), so this is the ACTIVE-LOW-DATA half of the 74181 truth
// table, where M high selects logic and CIN high adds one. Indexed by S3..S0 as
// the screen shows them (already inverted from the ALU S* lamps). "+" is
// addition, "|" OR; every DEC name in the microcode listing checks out against
// this table (A plus B = 9, A minus B minus 1 = 6, BL = 10, ABAR = 0, ...).
static const char aluLogic[16][7] PROGMEM = {
	"~A",     "~(A&B)", "~A|B",   "-1",     "~(A|B)", "~B",     "~(A^B)", "A|~B",
	"~A&B",   "A^B",    "B",      "A|B",    "0",      "A&~B",   "A&B",    "A",
};
// Arithmetic without carry in. With carry the result is one higher: a trailing
// "-1" is dropped, otherwise "+1" is appended.
static const char aluArith[16][11] PROGMEM = {
	"A-1",        "A&B-1",  "A&~B-1",     "-1",
	"A+(A|~B)",   "A&B+(A|~B)", "A-B-1",  "A|~B",
	"A+(A|B)",    "A+B",    "A&~B+(A|B)", "A|B",
	"A+A",        "A&B+A",  "A&~B+A",     "A",
};

// Cells left for the name on the ALU line. Five of the 32 arithmetic results
// have longer names ("A&~B+(A|B)+1" is 12); they show as "?", and the raw S,
// M and C beside them still say exactly what the ALU is doing. None of the
// five occurs in the microcode listing (the instruction-decode ROMs, which
// can also drive the ALU, are not transcribed).
#define ALU_NAME_W	9

// Names the ALU function into buf, space padded to ALU_NAME_W so it overwrites
// whatever the previous frame left there.
static void aluName(char *buf, uint8_t s, bool logic, bool carry) {
	uint8_t n;
	if(logic) {
		strcpy_P(buf, aluLogic[s]);
		n = strlen(buf);
	} else {
		strcpy_P(buf, aluArith[s]);
		n = strlen(buf);
		if(carry) {
			if(n == 2) {					// "-1" plus one
				strcpy(buf, "0");
				n = 1;
			} else if(buf[n - 2] == '-' && buf[n - 1] == '1') {
				n -= 2;
			} else {
				buf[n++] = '+';
				buf[n++] = '1';
			}
		}
	}
	if(n > ALU_NAME_W) {
		buf[0] = '?';
		n = 1;
	}
	while(n < ALU_NAME_W)
		buf[n++] = ' ';
	buf[n] = '\0';
}

// Everything on the main screen sits at a fixed place and is drawn only when
// what it shows changes, so a quiet machine costs no SPI traffic and a running
// one only repaints what moved. Each field remembers the key it was last drawn
// with: its value plus whether it is highlighted.
enum Field : uint8_t {
	F_MPC, F_AMUX, F_SPAD, F_SPWR, F_ALUS, F_ALUM, F_CIN, F_ALUNAME,
	F_EALU, F_AUXC, F_CNST, F_BUTIR, F_BUTJJ, F_BUTUN,
	F_MSYN, F_SSYN, F_BBSY, F_CYCLE, F_NXT, F_STATUS,
	F_COUNT
};

static uint32_t drawnKey[F_COUNT];
static bool screenDrawn;				// false: draw every field, and the labels

static bool fieldDue(Field f, uint32_t key) {
	if(screenDrawn && drawnKey[f] == key)
		return false;
	drawnKey[f] = key;
	return true;
}

static uint32_t fieldKey(uint16_t value, uint8_t style) {
	return (uint32_t) value | ((uint32_t) style << 16);
}

// Pixel layout: eight lines of the large font fill the 128 pixel height
// exactly, so lines are 16 apart with no extra gap. The font never uses the
// bottom row of its cell, which keeps the lines apart.
static const uint8_t ROW_H = 16;		// FontLarge.height
static const uint8_t GRID_Y = 3 * ROW_H;
static_assert(GRID_Y + 5 * ROW_H <= LCD_H, "the NXT line must be on the screen");
static const uint8_t GRID_COL1 = 45;
static const uint8_t GRID_COL2 = 99;

// One single-bit signal in the grid, highlighted when it changed.
struct GridFlag {
	const char *name;					// in flash
	uint16_t mask;
	uint8_t x;
	uint8_t row;
};

static const char nEALU[] PROGMEM = "EALU";
static const char nAUXC[] PROGMEM = "AUXC";
static const char nCNST[] PROGMEM = "CNST";
static const char nBUTIR[] PROGMEM = "BUTIR";
static const char nBUTJJ[] PROGMEM = "BUTJJ";
static const char nBUTUN[] PROGMEM = "BUTUN";
static const char nMSYN[] PROGMEM = "MSYN";
static const char nSSYN[] PROGMEM = "SSYN";
static const char nBBSY[] PROGMEM = "BBSY";

// One column per group: ALU and data path control, the microprogram branch
// tests, and the Unibus. In Field order from F_EALU on.
static const GridFlag gridFlags[] = {
	{ nEALU,  SIG_EALU,   0,         0 },
	{ nAUXC,  SIG_AUX_C,  0,         1 },
	{ nCNST,  SIG_CNST,   0,         2 },
	{ nBUTIR, SIG_BUT_IR, GRID_COL1, 0 },
	{ nBUTJJ, SIG_BUT_JJ, GRID_COL1, 1 },
	{ nBUTUN, SIG_BUT_UN, GRID_COL1, 2 },
	{ nMSYN,  SIG_MSYN,   GRID_COL2, 0 },
	{ nSSYN,  SIG_SSYN,   GRID_COL2, 1 },
	{ nBBSY,  SIG_BBSY,   GRID_COL2, 2 },
};

static void drawLabels(const Font *font) {
	lcdDrawText_P(0,  0,         PSTR("MPC"),  LCD_WHITE, currentBg, font);
	lcdDrawText_P(66, 0,         PSTR("AMUX"), LCD_WHITE, currentBg, font);
	lcdDrawText_P(0,  ROW_H,     PSTR("SPAD"), LCD_WHITE, currentBg, font);
	lcdDrawText_P(0,  2 * ROW_H, PSTR("ALU"),  LCD_WHITE, currentBg, font);
	lcdDrawText_P(32, 2 * ROW_H, PSTR("S"),    LCD_WHITE, currentBg, font);
	lcdDrawText_P(0,  GRID_Y + 4 * ROW_H, PSTR("NXT"), LCD_WHITE, currentBg, font);
}
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
int main() {
	resetDiag();
	clockInit();
	lcdInit();

#if DIAG_MODE == 4
	ramFloodLoop();
#elif DIAG_MODE == 3
	idReportLoop();
#elif DIAG_MODE == 2
	pinTestLoop();
#elif DIAG_MODE == 1
	diagLoop();
#else
#ifndef NO_I2C
	pcfInit();
	checkInit();
#endif
	lcdFill(LCD_BLACK);					// Clear screen
	for(;;) {
		// NO_I2C (make EXTRA=-DNO_I2C) leaves the expanders alone entirely, to
		// separate anything the bus does from anything the drawing does.
#ifndef NO_I2C
		KmSignals sample;
		pcfStatus = signalsRead(&sample);
		// Keep the state before the last change, not the last sample: when
		// single stepping the machine sits still between steps, and the
		// highlight has to stay until the next one.
		// The first sample has nothing to compare with and highlights nothing.
		static bool sampled;
		if(!sampled) {
			previousSignals = currentSignals = sample;
			sampled = true;
		} else if(!signalsEqual(sample, currentSignals)) {
			previousSignals = currentSignals;
			currentSignals = sample;
		}
		// A sample with an expander missing is not the machine: drop what the
		// check knows rather than learn from it.
		CheckResult check = { CHK_NONE, '?', 0, false, false };
		if(pcfStatus == 0)
			checkSample(sample, &check);
		else
			checkLost();
#else
		CheckResult check = { CHK_NONE, '?', 0, false, false };
#endif
		drawScreen(currentSignals, previousSignals, pcfStatus, check);
#if RESET_DIAG
		showResetDiag();
#endif
		_delay_ms(LOOP_DELAY_MS);
	}
	// textLoop();
#endif
}

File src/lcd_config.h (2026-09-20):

#ifndef LCD_CONFIG_H
#define LCD_CONFIG_H

// Hardware configuration for the KM11 display, taken from kicad/km1105 (the
// card) and kicad/kmdisp (the display board at the far end of the ribbon).
//
// The ATtiny1616 talks to the panel over SPI0 on its default port A mux, so no
// PORTMUX change is needed. Every display line leaves the ATtiny at 5V, goes
// through U10 (74LVC245 on the 3.3V rail) and reaches the ribbon header J2 at
// 3.3V; the display board's J2 has the same pinout and passes it straight to
// the module socket J1:
//
//   PA1  MOSI  -> U10 A2/B2 -> J2.13 -> kmdisp J1.4 (SDA)
//   PA2  MISO                            (unused by the display, it is write-only;
//                                         not on the ribbon)
//   PA3  SCK   -> U10 A1/B1 -> J2.11 -> kmdisp J1.3 (SCL)
//   PA4  SS    -> U10 A5/B5 -> J2.19 -> kmdisp J1.7 (CS), software controlled
//                                         (SPI0 SSD is set)
//   PB2  DC    -> U10 A4/B4 -> J2.17 -> kmdisp J1.6
//   PB3  RST   -> U10 A3/B3 -> J2.15 -> kmdisp J1.5, active low
//
// Every even J2 pin from 10 to 20 is GND, so each signal has a return next to
// it in the ribbon. The backlight is fed on the display board (J1.8 via R1 from
// +3.3V), so there is no pin for it here. PB4 and PB5 are spare and do not go
// to the ribbon; probe them at the chip.

#define LCD_SPI_PORT    PORTA
#define LCD_MOSI_bm     PIN1_bm
#define LCD_SCK_bm      PIN3_bm
#define LCD_CS_bm       PIN4_bm

#define LCD_CTRL_PORT   PORTB
#define LCD_DC_bm       PIN2_bm
#define LCD_RST_bm      PIN3_bm

// ---------------------------------------------------------------- the panel
//
// Two panels are described below; LCD_CONTROLLER picks one and everything else
// follows from it. The ST7735 is the 1.8" 128x160 board the KM11 uses - the
// display board and the 3d/ console are made for it. The ST7789P3 entry is a
// 2.25" 76x284 panel that was tried early on and never produced an image; it
// is kept for reference only.

#define LCD_ST7789      0
#define LCD_ST7735      1

#define LCD_CONTROLLER  LCD_ST7735

#if LCD_CONTROLLER == LCD_ST7789

// M35-2.25TFT-lanban, 2.25", 76x284 pixels, ST7789P3 controller.
#define LCD_PANEL_W     76
#define LCD_PANEL_H     284

// The ST7789 has 240x320 of frame memory and this panel is wired to a window
// inside it, so every address has to be shifted. These assume it sits centred:
// (240-76)/2 = 82 and (320-284)/2 = 18. Never confirmed on hardware - the panel
// has not produced an image yet.
#define LCD_COL_OFFSET  82
#define LCD_ROW_OFFSET  18

#define LCD_BGR         0
#define LCD_INVERT      1

// VCOM sets the LCD bias, and a value the glass does not like means no visible
// contrast at all - a controller that runs, accepts pixels and still shows
// plain white. Panel specific, and the first thing to sweep on a white screen:
// 0x19, 0x1A, 0x20, 0x28, 0x35.
#define LCD_VCOM        0x35

#else

// ST7735 board. Which panel it carries decides the size and the offsets, and
// the two common ones do not agree on either.
//
// 80x160 is the 0.96" size, and it sits in the middle of the frame memory.
// 128x160 is the classic 1.8" board, and it starts at the origin. A 1.8" board
// is far more often 128x160, so if this one shows a band down one side, or the
// image is shifted right by about a quarter of the screen, set this to 0.
#define LCD_ST7735_80x160  0

#if LCD_ST7735_80x160
	#define LCD_PANEL_W     80
	#define LCD_PANEL_H     160

	// The ST7735 has 132x162 of frame memory and this panel sits centred in it:
	// (132-80)/2 = 26, and one row down.
	#define LCD_COL_OFFSET  26
	#define LCD_ROW_OFFSET  1
#else
	#define LCD_PANEL_W     128
	#define LCD_PANEL_H     160

	// 128x160 fills the memory from the origin. Some boards ("green tab") want
	// 2 and 1 instead; a two pixel shift at one edge is the symptom.
	#define LCD_COL_OFFSET  0
	#define LCD_ROW_OFFSET  0
#endif

// This panel is wired red-green-blue. With BGR set it showed red and blue
// exchanged and green untouched - blue came out red, yellow came out cyan -
// which is the signature of that one bit. Other modules of the same type are
// genuinely BGR, so this is worth flipping if a replacement swaps its primaries.
//
// Inversion is off: with it on, this one showed every primary as its
// complement - red as cyan, green as magenta, blue as yellow. Plenty of 80x160
// modules do want it on, so it is worth flipping if a replacement panel comes
// out looking negative.
#define LCD_BGR         0
#define LCD_INVERT      0

#endif

// 0 and 2 are portrait, 1 and 3 are landscape. Landscape on the 128x160 ST7735
// gives 26 columns x 16 lines of 5x7 text; on the 80x160 ST7735 26 columns x 10
// lines, and on the ST7789P3 panel 47 columns x 9 lines.
#define LCD_ROTATION    1
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

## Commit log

2026-07-28 km11 initial
    [km11.kicad_pcb, km11.kicad_sch, km11.sch]
2026-07-28 First small parts
    [km11.kicad_sch]
2026-07-30 Add all flipchip signal names from Joergs sheet
    [km11.kicad_sch]
2026-07-30 All ports assigned
    [km11.kicad_sch]
2026-07-30 Initial routed
    [km11.kicad_pcb, km11.kicad_sch]
2026-07-31 Finished PCB with oddities removed
    [bom.csv, designators.csv, km11.kicad_pcb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]
2026-07-31 Many, many rounds of getting the 2.25 inch display to work, failed
    [kmmain.cpp, lcd_config.h, st7789.cpp]
2026-08-01 Implement expanders and read the signals
    [km1105.kicad_sch]
2026-08-01 Add a larger font, reformat screen, fix signal names on schematic
    [km1105.kicad_sch]
2026-08-01 Fix colors and spacing
    [kmmain.cpp]
2026-08-01 Small typo fixed; add more description in readme
    [km1105.kicad_pcb]
2026-08-08 Fixes to paths
    [km1105.sch]
2026-09-16 Bugfixes and 3d printed box
    [console_assembly.stl, console_lid.stl, console_pedestal.stl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]
2026-09-19 First attempt fixes
    [console_assembly.stl, console_shell.stl]
2026-09-19 Rename kicad project so that the display board can be added
    [bom.csv, designators.csv, km1105.csv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]
2026-09-20 Update the display board
    [km1105.kicad_pcb, km1105.kicad_sch, kmdisp.kicad_pcb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]
2026-09-20 Fix documentation according to latest layout; fix edge connectors with chamfers
    [bom.csv, designators.csv, km1105.kicad_pcb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]
2026-09-22 Remove debug from screen
    [km1105.kicad_pcb]
2026-09-22 Review against DEC KD11-B docs: fix ALU_S polarity, octal MPC, C0, AC LO
    Checked both boards and the firmware against EK-KD11B-MM-001, the 11/05
    print set (overlay drawings A-SS-5509081) and the KM11 W130/W131 prints;
    the full record is in review.md. Every J1 pin and the whole lamp map in
    km11-signals.txt verified correct. Corrections:
    - ALU S3..S0 are dim-when-asserted on the KM-2 overlay, i.e. active low;
    signals.cpp now inverts U5 P4..P7 like it does the MPC.
    - MPC is 8 bits and DEC quotes it in octal; it was shown as two decimal
    digits, which dropped the hundreds digit. Now 3 octal digits, and AMUX
    6 octal digits.
    - The KM-2 bus cycle bits are C1 and C0 (00 DATI, 01 DATIP, 10 DATO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
    [km1105.kicad_sch, kmdisp.kicad_pcb, kmdisp.kicad_sch]
2026-09-25 Remove old files
    [km1105.sch]
2026-09-30 Update 3d model for new display pcb
    [console_assembly.stl, console_base.stl, console_lid.stl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]
2026-10-01 Final version in its housing
2026-10-02 Decode bus cycle, ALU function and scratchpad register on the screen
    Show the C1/C0 Unibus cycle by name with its code (DATI=0 .. DATOB=3),
    lit while MSYN is asserted. Show the scratchpad address as DEC's octal
    register (R0..R17) with its use from KD11-B Table 4-3, and the ALU line
    as raw S (hex), M and C followed by the 74181 function from the
    active-low-data table, grey when EALU does not select the ALU.
    Flags are now yellow upper case when asserted and red lower case when
    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
2026-10-02 Show the next microstep's DEC tag and expanders that do not answer
    The bottom line names the microstep the MPC points at (NXT), from a
    256-entry tag table generated from the transcription of the KD11-B
    microcode listing, and lists in red any PCF8574 that failed to read,
    since its inputs then decode as plausible all-ones values.
    Claude-Session: https://claude.ai/code/session_01WhSd3J6tGbFqz7NroUynWi
    [kmmain.cpp]
2026-10-02 Highlight changed values, redraw only changed fields, fix NXT line
    Every field sits at a fixed position and is repainted only when its
    value or highlight changes, so a stopped machine causes no SPI traffic.
    Values that differ from the state before the last change get a dark
    blue background, which stays until the machine moves again, so a single
    step shows what it changed.
    The NXT/I2C line was drawn at y=125, below the 128 pixel screen; lines
    are now 16 pixels apart so all eight fit, with a static_assert on it.
    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
    [kmmain.cpp]
2026-10-02 Check the KM11 lamps against the KD11-B microcode while stepping
    While the 11/05 is single stepped, the word on the lamps (the one the
    MPC showed before the step) is compared with the microcode listing:
    ALU S/M/CIN where the instruction decode cannot be driving them, SPAD
    where the word supplies the address, the four BUT lamps and AUXC.
    Mismatches are drawn white on red, a next address the word cannot
    reach marks the MPC, and the status slot shows the revision and
    OK/BAD/SEQ?/--. Only settled samples count, so a running clock or a
    read straddling a step is not mistaken for a fault.
    Rev E and rev F differ only in AUX (and CKO) in 14 words; the revision
    is learnt from the AUXC lamp, kept in E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
    [kmmain.cpp]
2026-10-02 Note that the microcode transcription now reads BUT and BRG as printed
    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
2026-10-17 Show current MPC in addition to next one

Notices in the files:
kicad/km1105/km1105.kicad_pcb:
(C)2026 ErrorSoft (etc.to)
